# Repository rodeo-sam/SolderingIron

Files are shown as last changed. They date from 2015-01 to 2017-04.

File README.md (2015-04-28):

SolderingIron
=============

Idea for an OpenSource Soldering Iron

This project is just another avr based soldering iron. Since professional equipment is quite pricy and not very complicated this projects takes a good, changeable soldering iron tip like the Weller RT1 and provides all the electronics behind that.

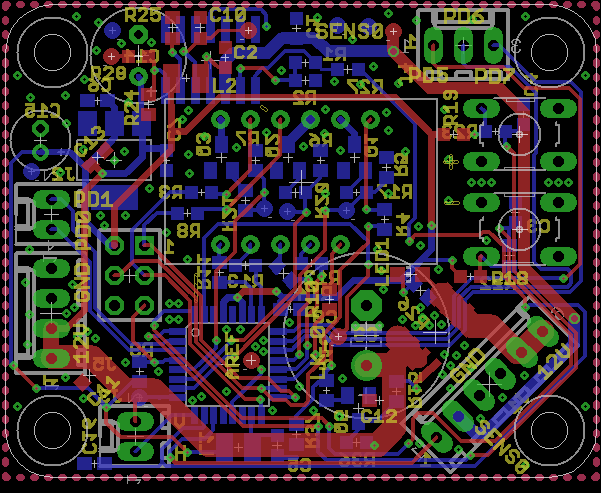
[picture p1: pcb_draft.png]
View on PCB Layout

## Features
* open hardware (schematic and layout made in Eagle 7.2 freeware license)
* open firmware written in C (not ready to use right now)
* fast heatup
* saving and restoring temperature to and from EEPROM
* high-precision op-amp for temperature measurement
* safety measures against overheating and controller crashes
* automatic temperature control (pid controller)
* different temperature scales available (recompiling necessary)
* solder tip rest detection via hall sensor (optional)
* almost all parts are available from the [Seeedstudio Open Parts Library](http://www.seeedstudio.com/wiki/Open_parts_library)

## How does it work
* 5V for logic
* 12V for soldering iron
* ATmega328p controlled

### Temperature measure
The thermo-voltage signal is amplified by an op-amp with a gain
	`g = 1 + R1/R2 = 1 + 51k/100 = 511`
this signal is converted by ADC0 using Vcc=5V as voltage reference

### Solder tip detection
Solved by a hall sensor connected to ADC2. This sensor is powered by 5V

## References
### Links:
* [arduino uno shield](http://www.martin-kumm.de/wiki/doku.php?id=Projects:SMD_Solderstation)
  * Forum discussion + group order coordination [Thema: DIY SMD - Lötstation Ersatz für (WELLER)](http://fpv-community.de/showthread.php?41335-DIY-SMD-Lötstation-Ersatz-für-(WELLER))
* [original Weller cable](http://www.pewa.de/cgi-bin/cosmoshop/lshop.cgi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)
* unfinished project [Custom Weller WSM 1 style controller for RT series tips](http://dangerousprototypes.com/forum/viewtopic.php?f=19&t=3583)
* [Thermoelement im Weller WMRP.](http://www.mikrocontroller.net/topic/175412#1686071)

### Datasheets:
* power MOSFET [IRF7424](http://www.irf.com/product-info/datasheets/data/irf7424.pdf)
* Voltage regulator [REG1117](http://www.ti.com/lit/pdf/SBVS001)
* uC [ATmega328P](http://www.atmel.com/devices/atmega328p.aspx)
* Quad OP-Amp [LM324D](http://pdf1.alldatasheet.com/datasheet-pdf/view/22759/STMICROELECTRONICS/LM324D.html)
* Single OP-Amp [OPA336u](http://www.ti.com/lit/ds/symlink/opa336.pdf)
* Solder Tip [Weller RT1](http://datasheet.octopart.com/RT1-Cooper-Tools-datasheet-13539183.pdf)
* Solder Tip detector [Hallsensor unipolar](http://www.reichelt.de/index.html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)

### Current State:
* hardware version 1.2 is almost ready to be produced
* optimized bill of materials by reducing unnecessary components
* PCB measures 5cm x 5cm
* individual 7-segment displays in use (broader availability)
* I2C is now unused and can be used for additional hardware

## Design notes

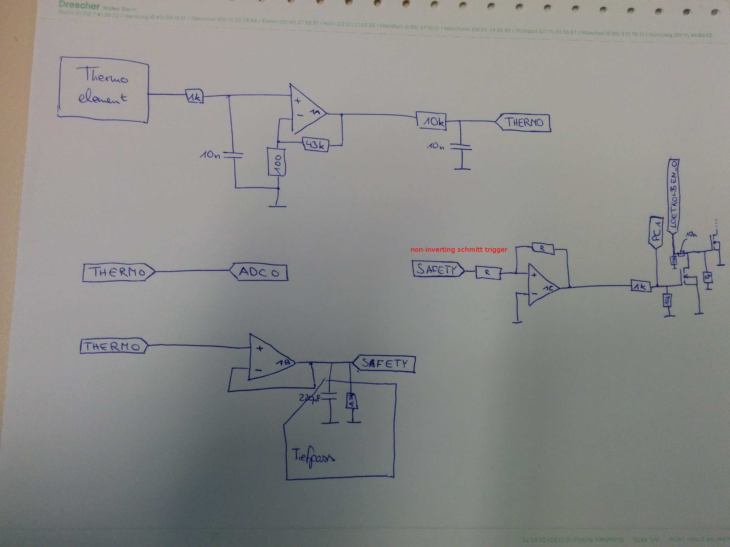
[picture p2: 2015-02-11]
Hardware/img/safety.jpg

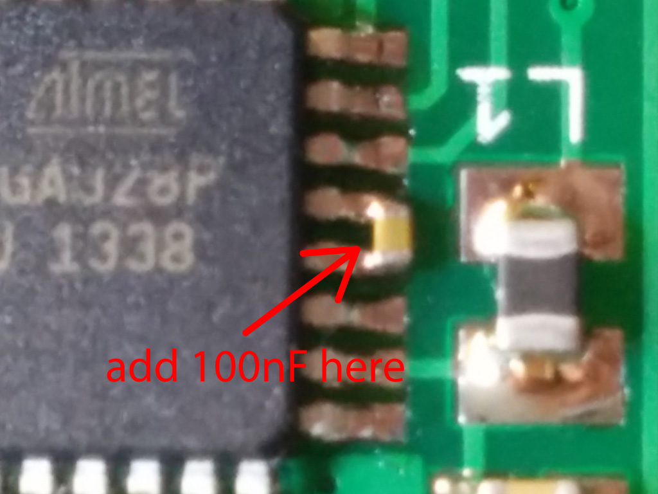
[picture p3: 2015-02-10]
Hardware/img/aref.jpg

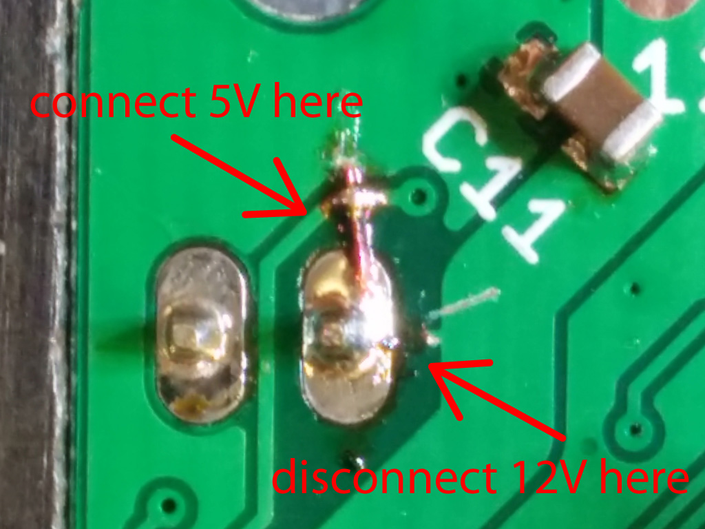
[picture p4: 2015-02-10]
Hardware/img/hall.jpg

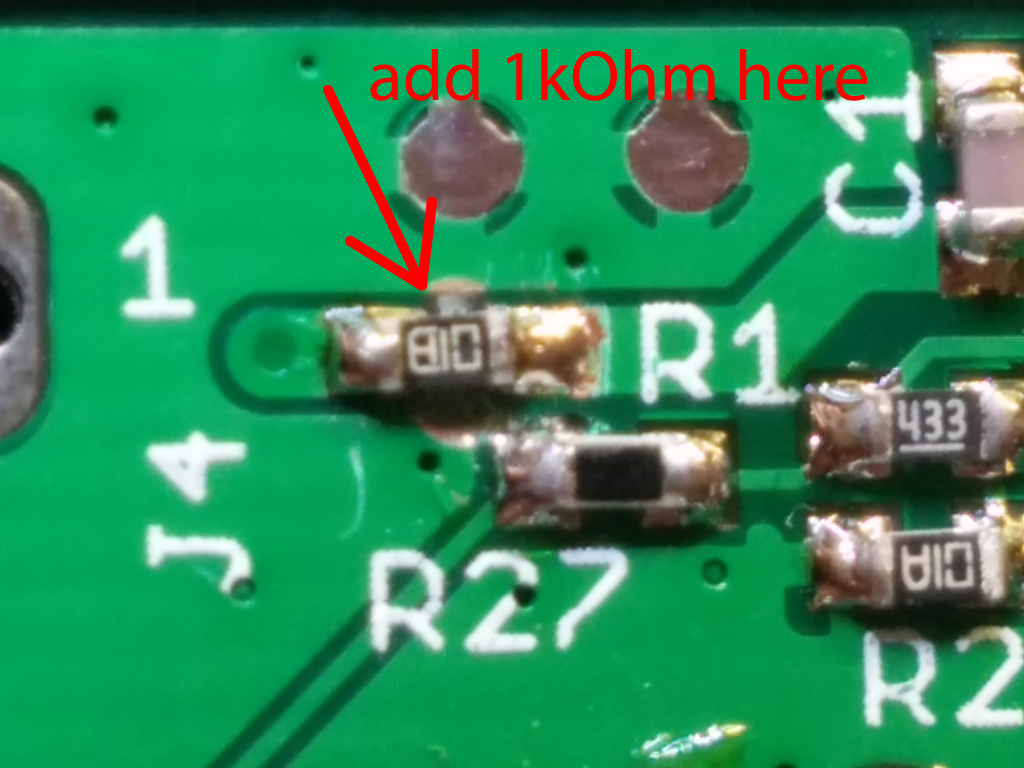
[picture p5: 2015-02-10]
Hardware/img/low_pass.jpg

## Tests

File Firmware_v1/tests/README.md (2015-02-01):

SolderingIron tests
=============

This is the place to store your unit test like test files

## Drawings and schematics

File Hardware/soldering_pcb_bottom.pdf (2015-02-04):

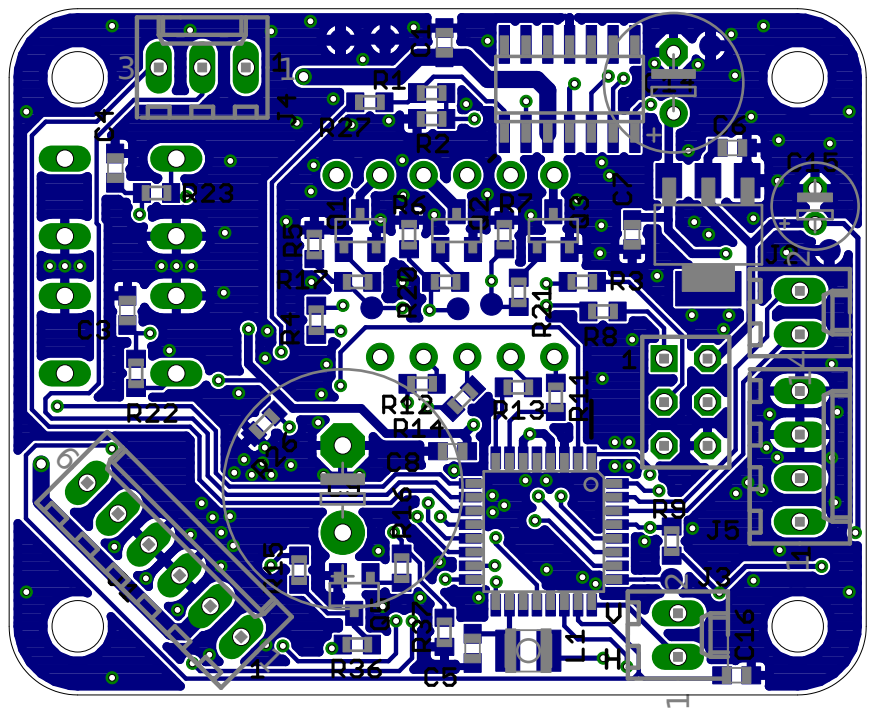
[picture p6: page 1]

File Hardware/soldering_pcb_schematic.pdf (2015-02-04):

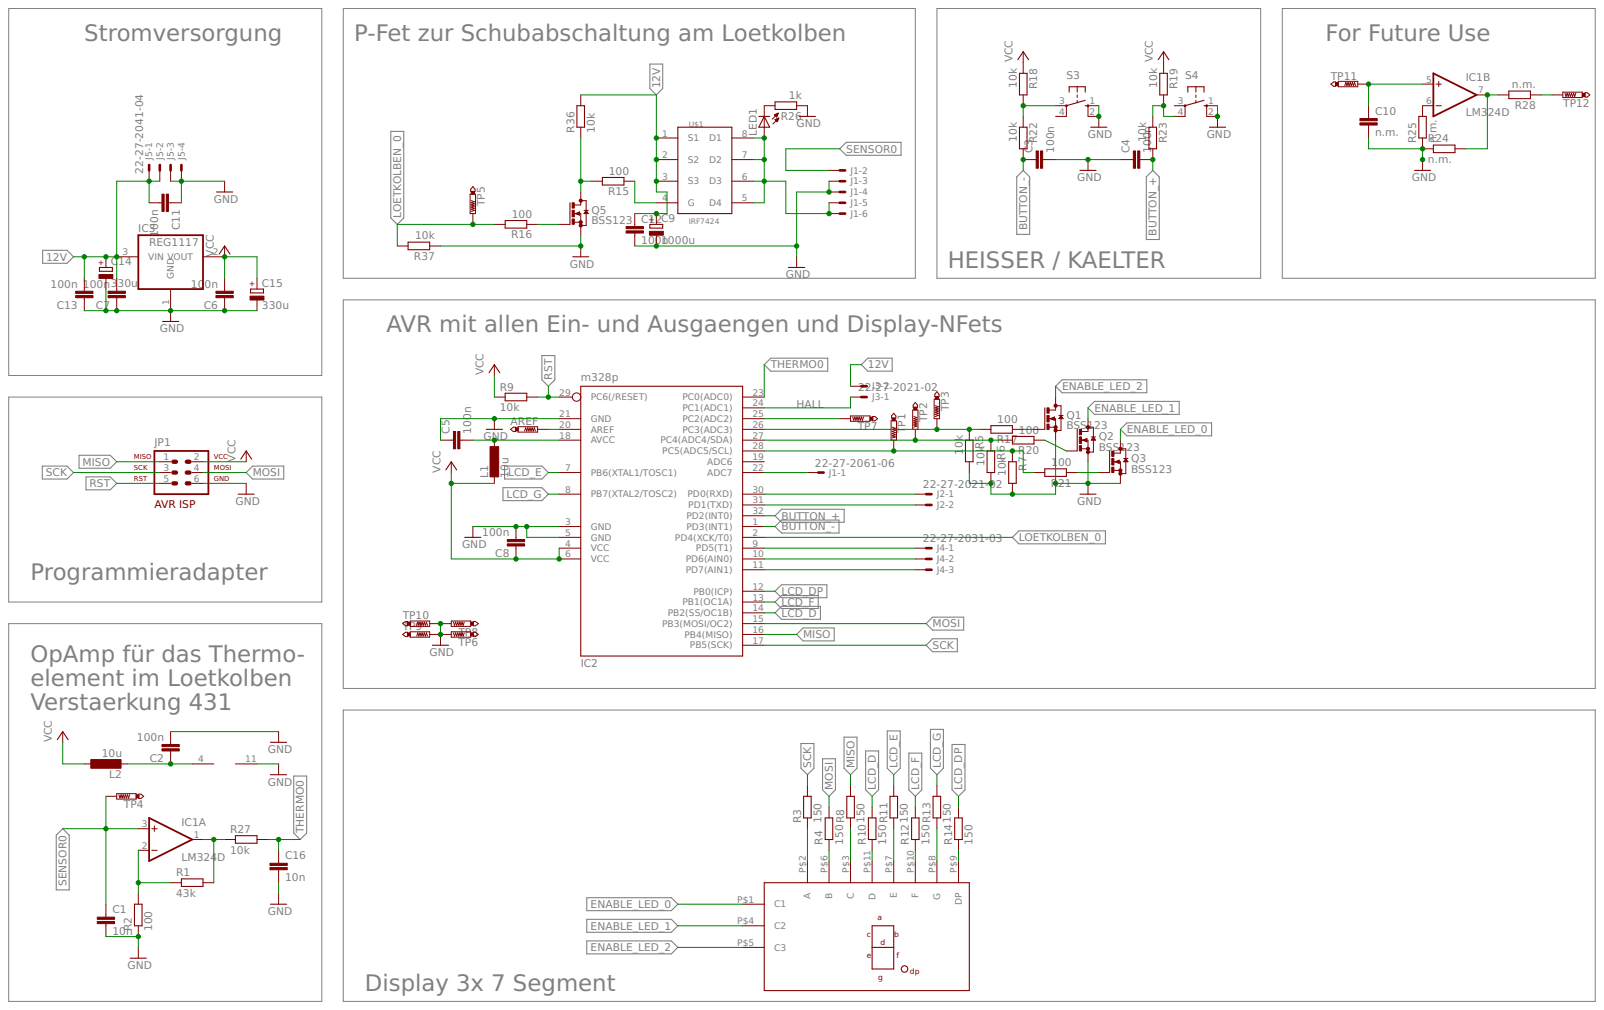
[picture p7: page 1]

AVR mit allen Ein- und Ausgaengen und Display-NFets

OpAmp für das Thermo- element im Loetkolben
Verstaerkung 431

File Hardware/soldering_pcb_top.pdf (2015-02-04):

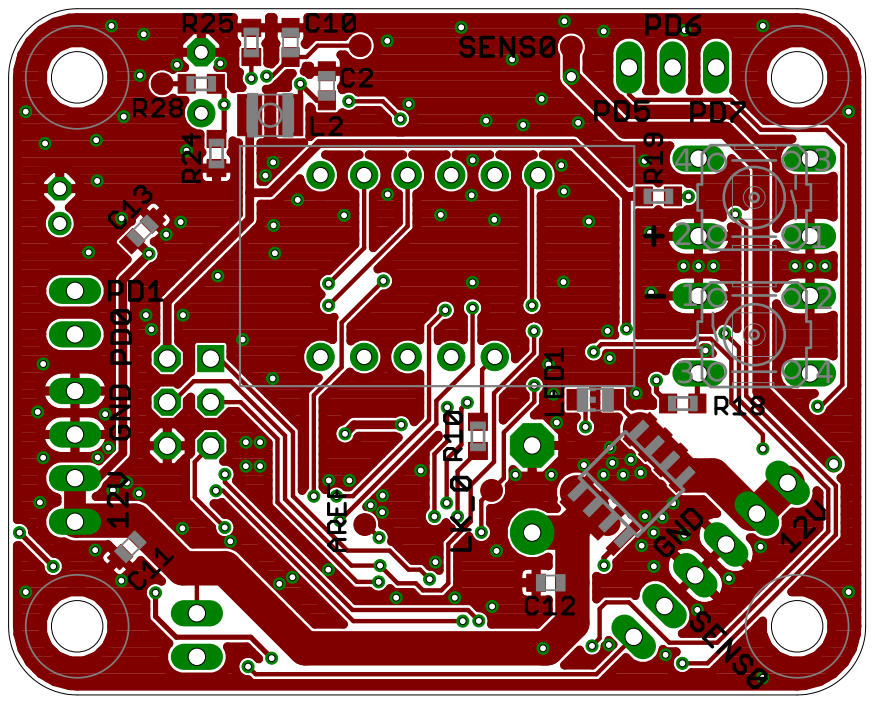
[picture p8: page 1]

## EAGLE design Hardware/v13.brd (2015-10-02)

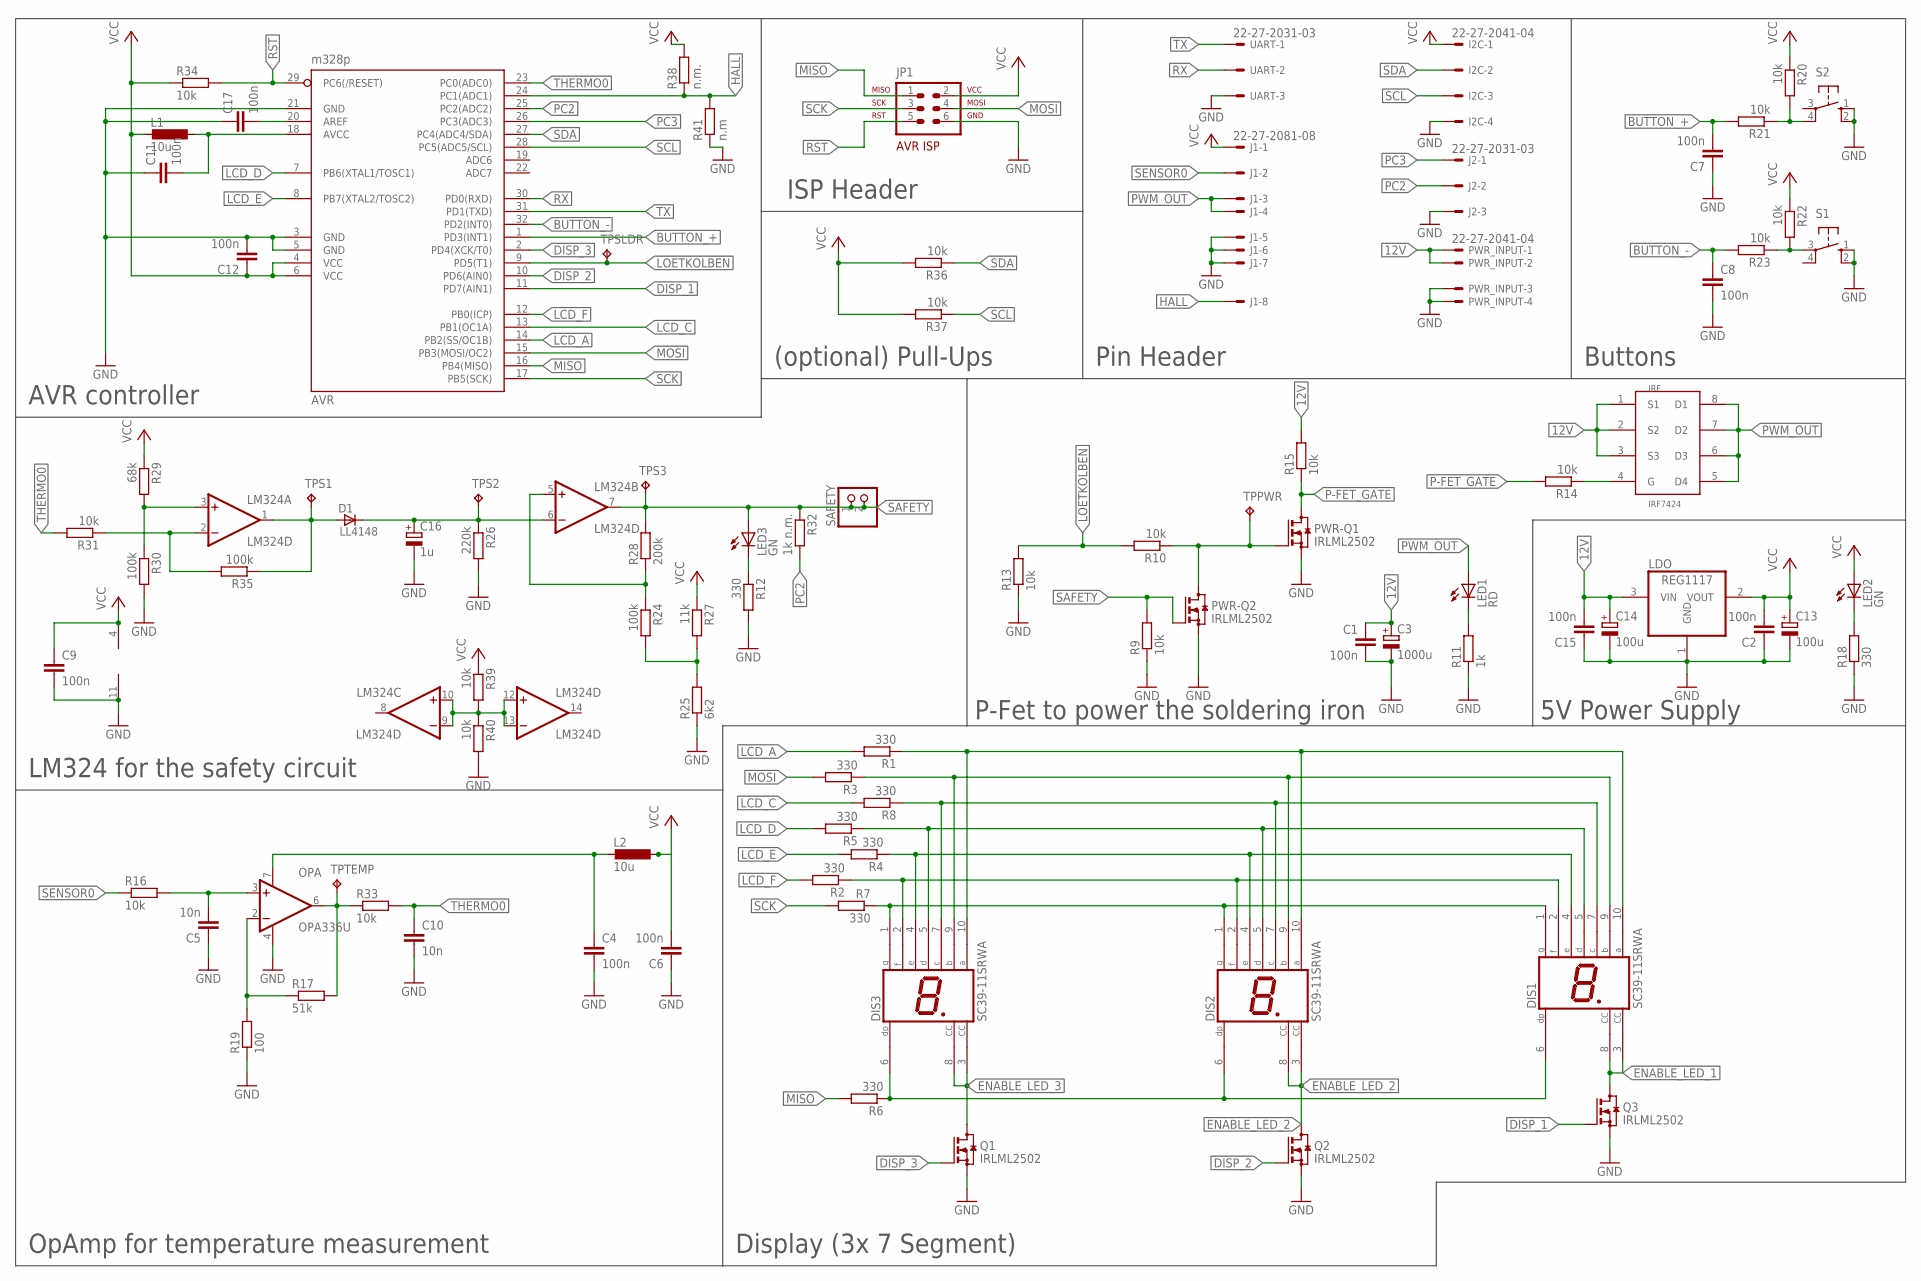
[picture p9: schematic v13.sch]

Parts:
AVR: m328p; TQFP32-08
C1, C2, C4, C6, C7, C8, C9, C11, C12, C15, C17: 100n; C0603
C3: 1000u; E5-13
C5, C10: 10n; C0603
C13, C14: 100u; E2-5
C16: 1u; E2-5
D1: LL4148; SOD80_DO213AA_MINIMELF
DIS1, DIS2, DIS3: SC39-11SRWA; HDSP-E
I2C: 22-27-2041-04; 6410-04
IRF: IRF7424; SO-08
J1: 22-27-2081-08; 6410-08
J2: 22-27-2031-03; 6410-03
JP1: AVR-ISP-6VERT; AVR-ISP-6
L1, L2: 10u; L2825P
LDO: REG1117; SOT223
LED1: RD; CHIP-LED0805
LED2, LED3: GN; CHIP-LED0805
LM324: LM324D; SO14
OPA: OPA336U; SO08
PWR-Q1, PWR-Q2: IRLML2502; SOT23
PWR_INPUT: 22-27-2041-04; 6410-04
Q1, Q2, Q3: IRLML2502; SOT23
R1, R2, R3, R4, R5, R6, R7, R8, R12, R18: 330; R0603
R9, R10, R13, R14, R15, R16, R20, R21, R22, R23, R31, R33, R34, R36, R37, R39, R40: 10k; R0603
R11: 1k; R0603
R17: 51k; R0603
R19: 100; R0603
R24, R30, R35: 100k; R0603
R25: 6k2; R0603
R26: 220k; R0603
R27: 11k; R0603
R28: 200k; R0603
R29: 68k; R0603
R32: 1k n.m.; R0603
R38: n.m.; R0603
R41: n.m; R0603
S1, S2: 10-XX; B3F-10XX
SAFETY: PINHD-1X2; 1X02
TPPWR: TPB1,27; B1,27
TPS1, TPS2, TPS3: TPB1,27; B1,27
TPSLDR: TPB1,27; B1,27
TPTEMP: TPB1,27; B1,27
UART: 22-27-2031-03; 6410-03

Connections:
12V: C1.1, C3.+, C14.+, C15.2, IRF.1 (S1), IRF.2 (S2), IRF.3 (S3), LDO.3 (VIN), PWR_INPUT.1, PWR_INPUT.2, R15.2
AREF: AVR.20 (AREF), C17.2
AVCC: AVR.18 (AVCC), C11.2, L1.1
BUTTON_+: AVR.1 (PD3(INT1)), C7.2, R21.2
BUTTON_-: AVR.32 (PD2(INT0)), C8.1, R23.2
DISP_1: AVR.11 (PD7(AIN1)), Q3.1 (G)
DISP_2: AVR.10 (PD6(AIN0)), Q2.1 (G)
DISP_3: AVR.2 (PD4(XCK/T0)), Q1.1 (G)
ENABLE_LED_1: DIS1.3 (CC), DIS1.8 (CC), Q3.3 (D)
ENABLE_LED_2: DIS2.3 (CC), DIS2.8 (CC), Q2.3 (D)
ENABLE_LED_3: DIS3.3 (CC), DIS3.8 (CC), Q1.3 (D)
GND: AVR.3 (GND), AVR.5 (GND), AVR.21 (GND), C1.2, C2.1, C3.-, C4.2, C5.1, C6.1, C7.1, C8.2, C9.2, C10.2, C11.1, C12.2, C13.-, C14.-, C15.1, C16.-, C17.1, I2C.4, J1.5, J1.6, J1.7, J2.3, JP1.6, LDO.1 (GND), LM324.11 (V-), OPA.4 (V-), PWR-Q1.2 (S), PWR-Q2.2 (S), PWR_INPUT.3, PWR_INPUT.4, Q1.2 (S), Q2.2 (S), Q3.2 (S), R9.1, R11.1, R12.2, R13.1, R18.1, R19.1, R25.1, R26.2, R30.2, R40.2, R41.1, S1.1 (S), S1.2 (S1), S2.1 (S), S2.2 (S1), UART.3
HALL: AVR.24 (PC1(ADC1)), J1.8, R38.1, R41.2
LCD_A: AVR.14 (PB2(SS/OC1B)), R1.2
LCD_C: AVR.13 (PB1(OC1A)), R8.2
LCD_D: AVR.7 (PB6(XTAL1/TOSC1)), R5.2
LCD_E: AVR.8 (PB7(XTAL2/TOSC2)), R4.2
LCD_F: AVR.12 (PB0(ICP)), R2.2
LOETKOLBEN: AVR.9 (PD5(T1)), R10.2, R13.2, TPSLDR.TP
MISO: AVR.16 (PB4(MISO)), JP1.1, R6.2
MOSI: AVR.15 (PB3(MOSI/OC2)), JP1.4, R3.2
unnamed: OPA.2 (-IN), R17.1, R19.2
unnamed: LED3.C, R12.1
unnamed: LM324.2 (-IN), R31.1, R35.2
unnamed: LM324.9 (-IN), LM324.10 (+IN), LM324.12 (+IN), LM324.13 (-IN), R39.2, R40.1
unnamed: C4.1, L2.2, OPA.7 (V+)
unnamed: D1.A, LM324.1 (OUT), R35.1, TPS1.TP
unnamed: LM324.3 (+IN), R29.2, R30.1
unnamed: C16.+, D1.C, LM324.6 (-IN), R26.1, TPS2.TP
unnamed: LM324.5 (+IN), R24.1, R28.1
unnamed: R24.2, R25.2, R27.2
unnamed: IRF.4 (G), R14.1
unnamed: PWR-Q1.1 (G), PWR-Q2.3 (D), R10.1, TPPWR.TP
unnamed: R22.2, R23.1, S1.3
unnamed: R20.2, R21.1, S2.4 (P1)
unnamed: LED2.C, R18.2
unnamed: LED1.C, R11.2
unnamed: C5.2, OPA.3 (+IN), R16.2
unnamed: DIS1.6 (DP), DIS2.6 (DP), DIS3.6 (DP), R6.1
unnamed: DIS1.2 (F), DIS2.2 (F), DIS3.2 (F), R2.1
unnamed: DIS1.1 (G), DIS2.1 (G), DIS3.1 (G), R7.1
unnamed: DIS1.4 (E), DIS2.4 (E), DIS3.4 (E), R4.1
unnamed: DIS1.5 (D), DIS2.5 (D), DIS3.5 (D), R5.1
unnamed: DIS1.7 (C), DIS2.7 (C), DIS3.7 (C), R8.1
unnamed: DIS1.9 (B), DIS2.9 (B), DIS3.9 (B), R3.1
unnamed: DIS1.10 (A), DIS2.10 (A), DIS3.10 (A), R1.1
OPA_OUT: OPA.6 (OUT), R17.2, R33.1, TPTEMP.TP
P-FET_GATE: PWR-Q1.3 (D), R14.2, R15.1
PC2: AVR.25 (PC2(ADC2)), J2.2, R32.2
PC3: AVR.26 (PC3(ADC3)), J2.1
PWM_OUT: IRF.5 (D4), IRF.6 (D3), IRF.7 (D2), IRF.8 (D1), J1.3, J1.4, LED1.A
RST: AVR.29 (PC6(/RESET)), JP1.5, R34.2
RX: AVR.30 (PD0(RXD)), UART.2
SAFETY: LED3.A, LM324.7 (OUT), PWR-Q2.1 (G), R9.2, R28.2, R32.1, SAFETY.1, SAFETY.2, TPS3.TP
SCK: AVR.17 (PB5(SCK)), JP1.3, R7.2
SCL: AVR.28 (PC5(ADC5/SCL)), I2C.3, R37.1
SDA: AVR.27 (PC4(ADC4/SDA)), I2C.2, R36.1
SENSOR0: J1.2, R16.1
THERMO0: AVR.23 (PC0(ADC0)), C10.1, R31.2, R33.2
TX: AVR.31 (PD1(TXD)), UART.1
VCC: AVR.4 (VCC), AVR.6 (VCC), C2.2, C6.2, C9.1, C12.1, C13.+, I2C.1, J1.1, JP1.2, L1.2, L2.1, LDO.2 (VOUT), LED2.A, LM324.4 (V+), R20.1, R22.1, R27.1, R29.1, R34.1, R36.2, R37.2, R38.2, R39.1

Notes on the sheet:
Buttons
AVR controller
P-Fet to power the soldering iron
5V Power Supply
ISP Header
OpAmp for temperature measurement
Display (3x 7 Segment)
Pin Header
LM324 for the safety circuit
(optional) Pull-Ups

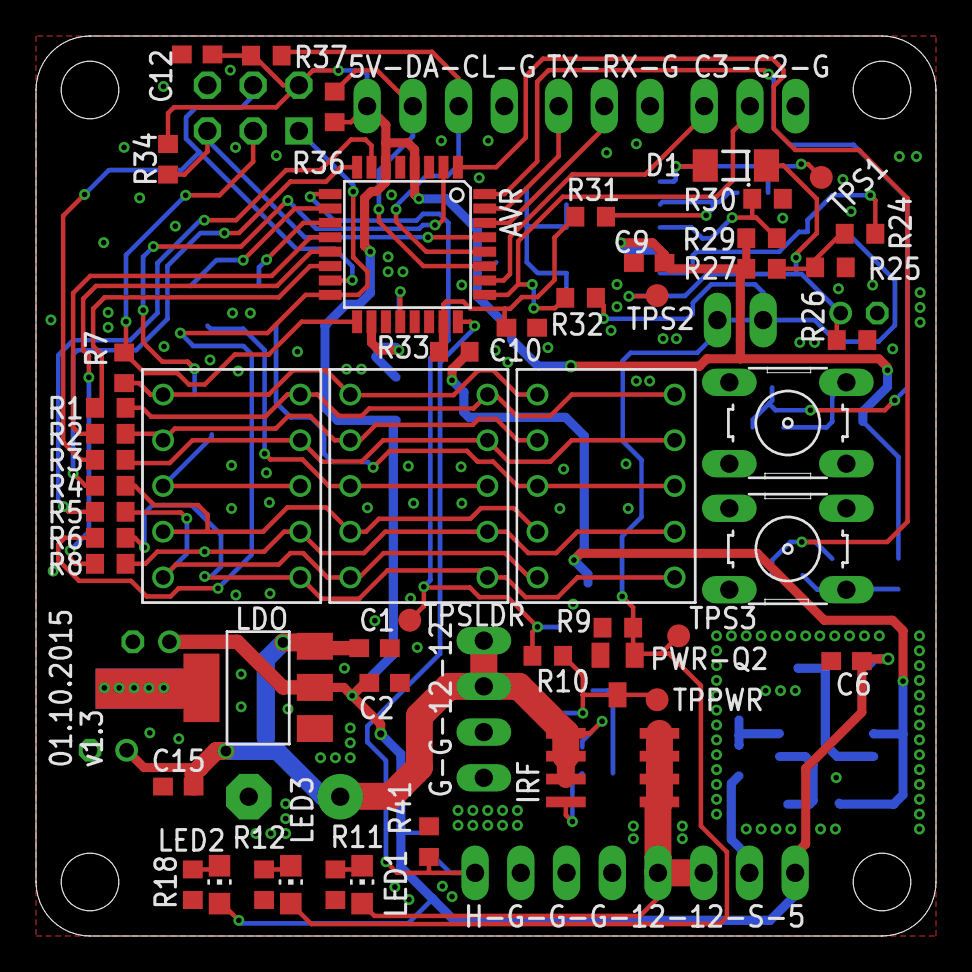
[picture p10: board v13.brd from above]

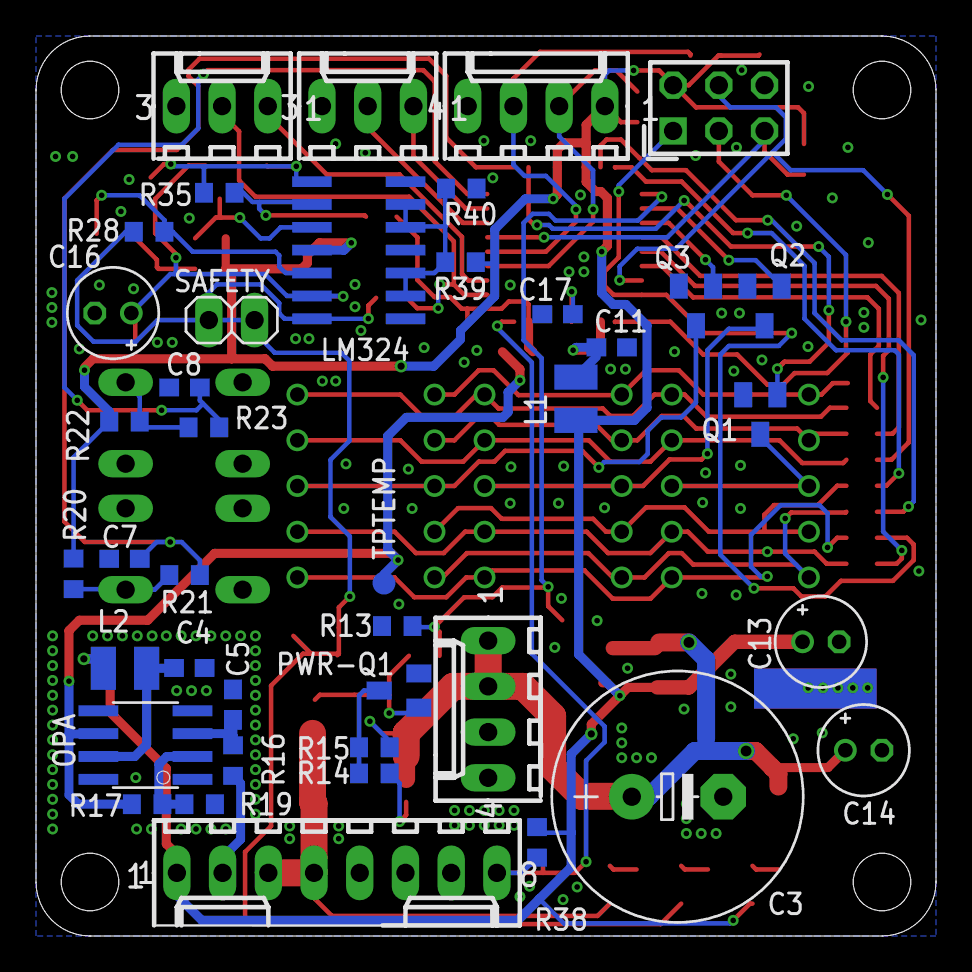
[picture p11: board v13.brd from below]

Board: 4 copper layers, 50.0 x 50.0 mm, 92 parts (41 on the bottom side), 61 nets.

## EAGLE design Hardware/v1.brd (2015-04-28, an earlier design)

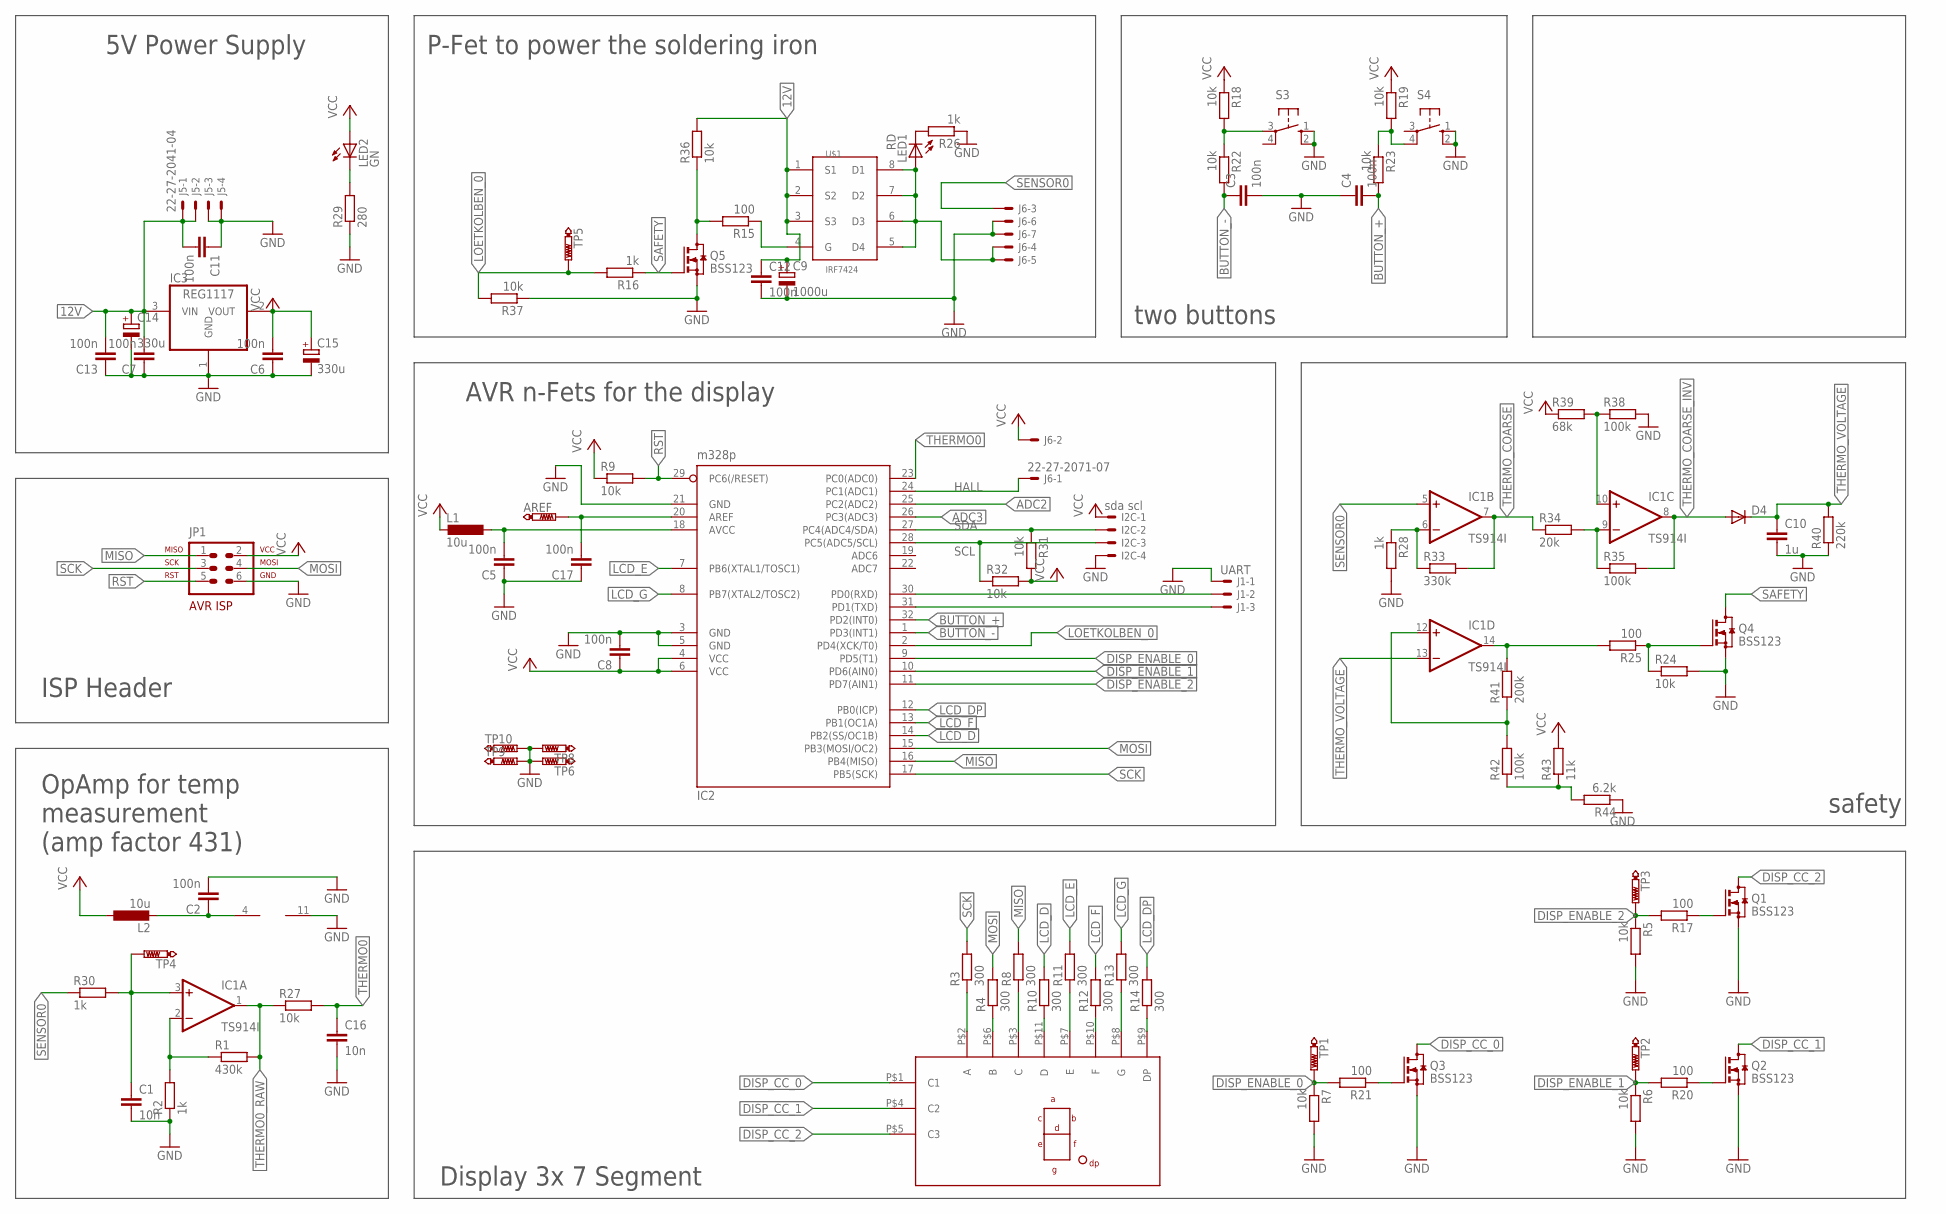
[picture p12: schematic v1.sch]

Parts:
AREF: PTR1B1,27; B1,27
C1, C16: 10n; C0603
C2, C3, C4, C5, C6, C7, C8, C11, C12, C13, C17: 100n; C0603
C9: 1000u; E5-13
C10: 1u; C0805
C14: 330u; E3,5-8
C15: 330u; E2-5
D4: DIODE-DO214AC; DO214AC
I2C: sda scl; 6410-04
IC1: TS914I; SO14
IC2: m328p; TQFP32-08
IC3: REG1117; SOT223
J1: UART; 6410-03
J5: 22-27-2041-04; 6410-04
J6: 22-27-2071-07; 6410-07
JP1: AVR-ISP-6VERT; AVR-ISP-6
L1, L2: 10u; L2825P
LED1: RD; CHIP-LED0805
LED2: GN; CHIP-LED0805
Q1, Q2, Q3, Q4, Q5: BSS123; SOT23
R1: 430k; R0603
R2, R16, R26, R28, R30: 1k; R0603
R3, R4, R8, R10, R11, R12, R13, R14: 300; R0603
R5, R6, R7, R9, R18, R19, R22, R23, R24, R27, R31, R32, R36, R37: 10k; R0603
R15, R17, R20, R21, R25: 100; R0603
R29: 280; R0603
R33: 330k; R0603
R34: 20k; R0603
R35, R38, R42: 100k; R0603
R39: 68k; R0603
R40: 220k; R0603
R41: 200k; R0603
R43: 11k; R0603
R44: 6.2k; R0603
S3, S4: 10-XX; B3F-10XX
TP1, TP2, TP3, TP4, TP5, TP6, TP8, TP9, TP10: PTR1B1,27; B1,27
U$1: IRF7424; SO-08
U$2: 3X7SEG

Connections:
12V: C7.2, C9.+, C11.2, C12.1, C13.2, C14.+, IC3.3 (VIN), J5.1, J5.2, R36.2, U$1.1 (S1), U$1.2 (S2), U$1.3 (S3)
ADC2: IC2.25 (PC2(ADC2))
ADC3: IC2.26 (PC3(ADC3))
AREF: AREF.TP, C17.2, IC2.20 (AREF)
BUTTON_+: C4.2, IC2.32 (PD2(INT0)), R23.2
BUTTON_-: C3.1, IC2.1 (PD3(INT1)), R22.2
DISP_CC_0: Q3.3 (D), U$2.P$1 (C1)
DISP_CC_1: Q2.3 (D), U$2.P$4 (C2)
DISP_CC_2: Q1.3 (D), U$2.P$5 (C3)
DISP_ENABLE_0: IC2.9 (PD5(T1)), R7.1, R21.2, TP1.TP
DISP_ENABLE_1: IC2.10 (PD6(AIN0)), R6.1, R20.2, TP2.TP
DISP_ENABLE_2: IC2.11 (PD7(AIN1)), R5.1, R17.2, TP3.TP
GND: C1.2, C2.2, C3.2, C4.1, C5.1, C6.1, C7.1, C8.2, C9.-, C10.2, C11.1, C12.2, C13.1, C14.-, C15.-, C16.2, C17.1, I2C.4, IC1.11 (V-), IC2.3 (GND), IC2.5 (GND), IC2.21 (GND), IC3.1 (GND), J1.1, J5.3, J5.4, J6.6, J6.7, JP1.6, Q1.2 (S), Q2.2 (S), Q3.2 (S), Q4.2 (S), Q5.2 (S), R2.1, R5.2, R6.2, R7.2, R24.2, R26.1, R28.2, R29.1, R37.1, R38.2, R40.1, R44.1, S3.1 (S), S3.2 (S1), S4.1 (S), S4.2 (S1), TP6.TP, TP8.TP, TP9.TP, TP10.TP
HALL: IC2.24 (PC1(ADC1)), J6.1
LCD_D: IC2.14 (PB2(SS/OC1B)), R10.2
LCD_DP: IC2.12 (PB0(ICP)), R14.2
LCD_E: IC2.7 (PB6(XTAL1/TOSC1)), R11.2
LCD_F: IC2.13 (PB1(OC1A)), R12.2
LCD_G: IC2.8 (PB7(XTAL2/TOSC2)), R13.2
LOETKOLBEN_0: IC2.2 (PD4(XCK/T0)), R16.2, R37.2, TP5.TP
MISO: IC2.16 (PB4(MISO)), JP1.1, R8.2
MOSI: IC2.15 (PB3(MOSI/OC2)), JP1.4, R4.2
unnamed: IC1.2 (-IN), R1.1, R2.2
unnamed: IC2.31 (PD1(TXD)), J1.3
unnamed: C5.2, IC2.18 (AVCC), L1.1
unnamed: IC2.30 (PD0(RXD)), J1.2
unnamed: C2.1, IC1.4 (V+), L2.2
unnamed: R3.1, U$2.P$2 (A)
unnamed: R4.1, U$2.P$6 (B)
unnamed: R8.1, U$2.P$3 (C)
unnamed: R10.1, U$2.P$11 (D)
unnamed: Q4.1 (G), R24.1, R25.1
unnamed: R11.1, U$2.P$7 (E)
unnamed: R12.1, U$2.P$10 (F)
unnamed: R13.1, U$2.P$8 (G)
unnamed: R14.1, U$2.P$9 (DP)
unnamed: R15.1, U$1.4 (G)
unnamed: IC1.6 (-IN), R28.1, R33.1
unnamed: Q2.1 (G), R20.1
unnamed: Q1.1 (G), R17.1
unnamed: Q3.1 (G), R21.1
unnamed: IC1.9 (-IN), R34.2, R35.1
unnamed: IC1.12 (+IN), R41.1, R42.2
unnamed: R18.2, R22.1, S3.3
unnamed: R19.2, R23.1, S4.4 (P1)
unnamed: LED2.C, R29.2
unnamed: LED1.C, R26.2
unnamed: IC1.10 (+IN), R38.1, R39.2
unnamed: C1.1, IC1.3 (+IN), R30.2, TP4.TP
unnamed: R42.1, R43.1, R44.2
unnamed: IC1.14 (OUT), R25.2, R41.2
unnamed: Q5.3 (D), R15.2, R36.1
unnamed: J6.4, J6.5, LED1.A, U$1.5 (D4), U$1.6 (D3), U$1.7 (D2), U$1.8 (D1)
RST: IC2.29 (PC6(/RESET)), JP1.5, R9.2
SAFETY: Q4.3 (D), Q5.1 (G), R16.1
SCK: IC2.17 (PB5(SCK)), JP1.3, R3.2
SCL: I2C.3, IC2.28 (PC5(ADC5/SCL)), R32.1
SDA: I2C.2, IC2.27 (PC4(ADC4/SDA)), R31.1
SENSOR0: IC1.5 (+IN), J6.3, R30.1
THERMO0: C16.1, IC2.23 (PC0(ADC0)), R27.2
THERMO0_RAW: IC1.1 (OUT), R1.2, R27.1
THERMO_COARSE: IC1.7 (OUT), R33.2, R34.1
THERMO_COARSE_INV: D4.A, IC1.8 (OUT), R35.2
THERMO_VOLTAGE: C10.1, D4.C, IC1.13 (-IN), R40.2
VCC: C6.2, C8.1, C15.+, I2C.1, IC2.4 (VCC), IC2.6 (VCC), IC3.2 (VOUT), J6.2, JP1.2, L1.2, L2.1, LED2.A, R9.1, R18.1, R19.1, R31.2, R32.2, R39.1, R43.2

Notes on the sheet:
two buttons
AVR n-Fets for the display
P-Fet to power the soldering iron
5V Power Supply
ISP Header
OpAmp for temp measurement (amp factor 431)
Display 3x 7 Segment
safety

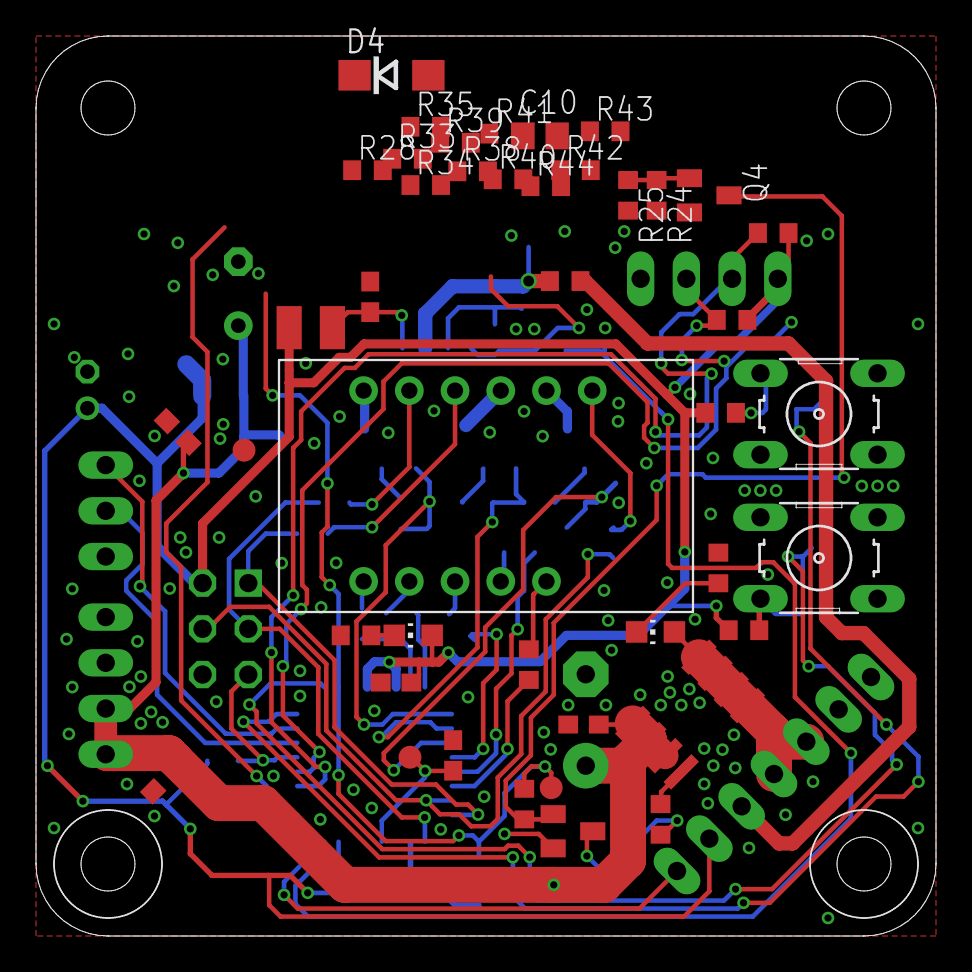
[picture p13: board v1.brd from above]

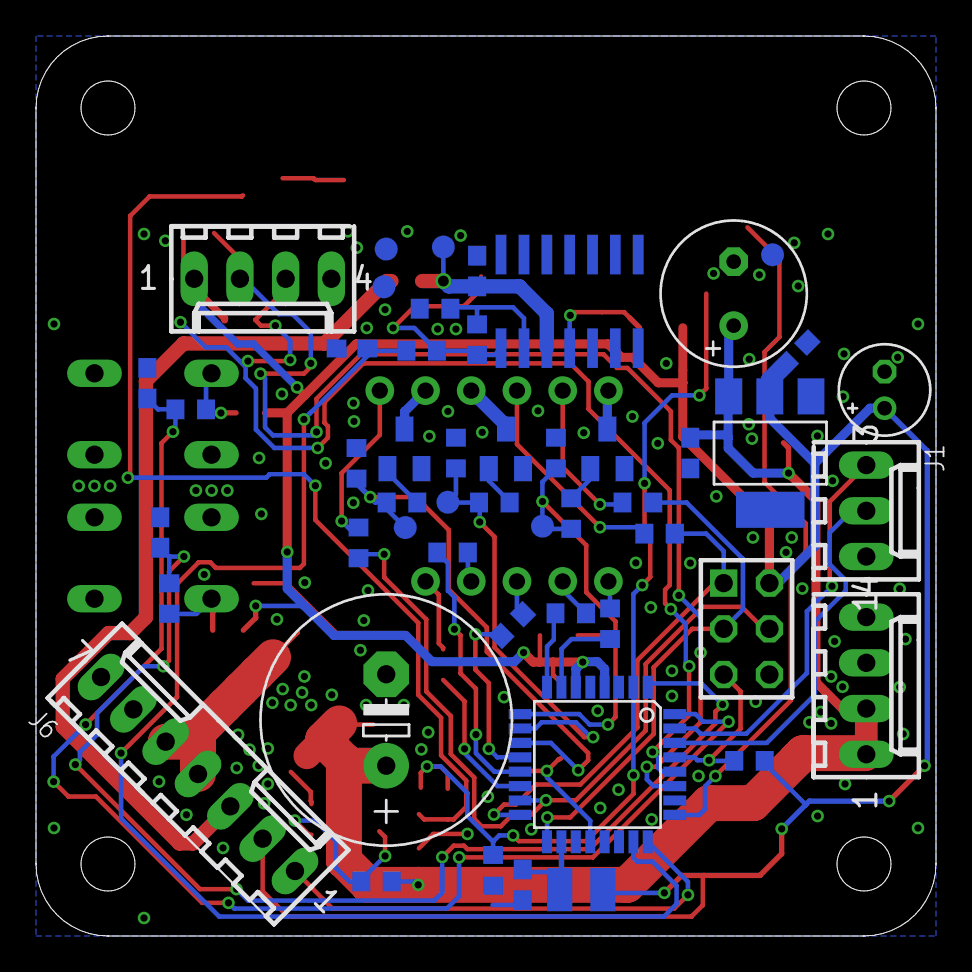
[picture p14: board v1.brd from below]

Board: 2 copper layers, 50.0 x 50.0 mm, 93 parts (50 on the bottom side), 63 nets.

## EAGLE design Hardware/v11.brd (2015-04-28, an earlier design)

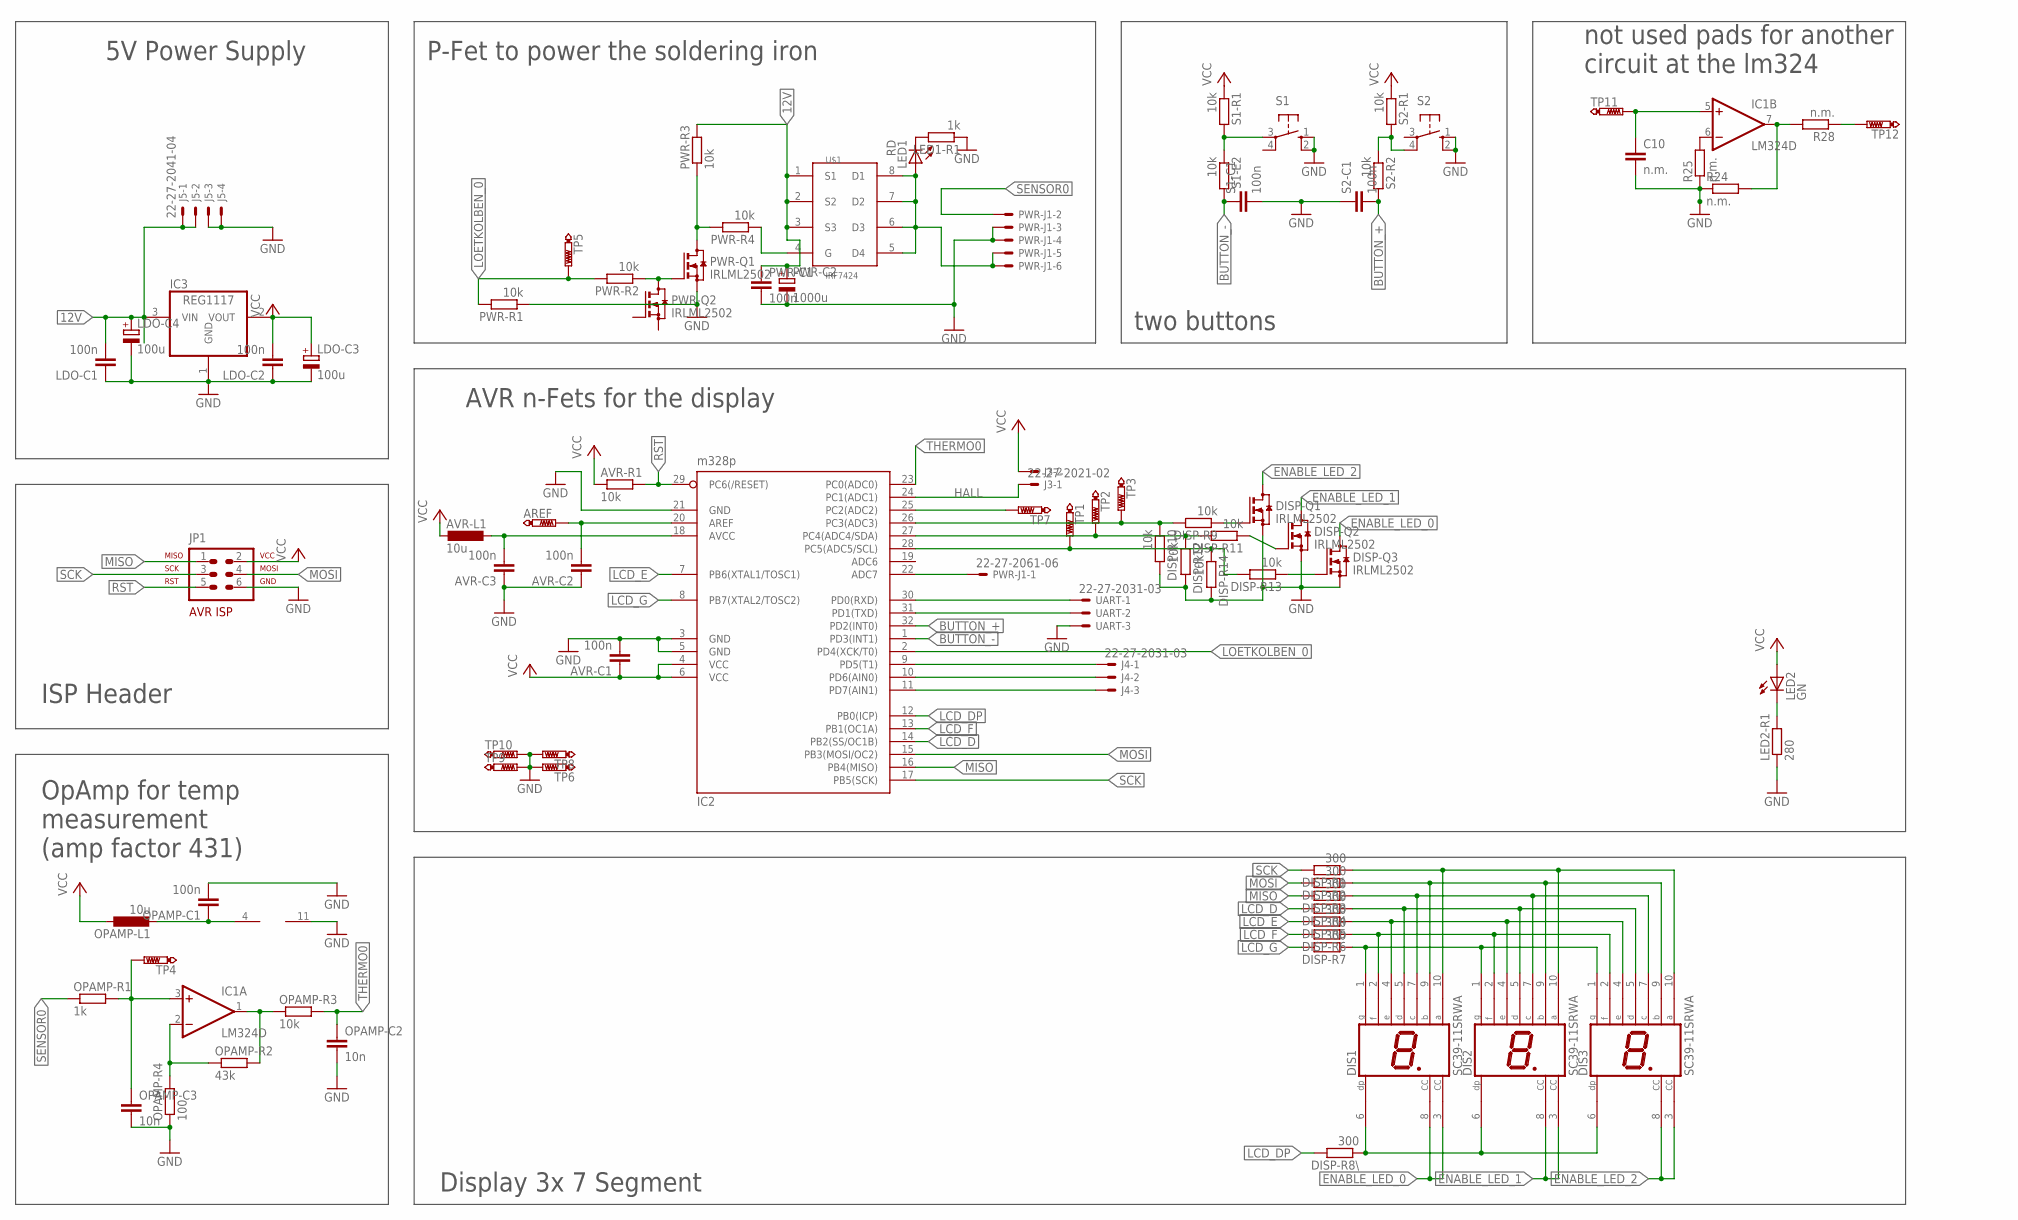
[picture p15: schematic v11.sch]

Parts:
AREF: PTR1B1,27; B1,27
AVR-C1, AVR-C2, AVR-C3: 100n; C0603
AVR-L1: 10u; L2825P
AVR-R1: 10k; R0603
C10: n.m.; C0603
DIS1, DIS2, DIS3: SC39-11SRWA; HDSP-E
DISP-Q1, DISP-Q2, DISP-Q3: IRLML2502; SOT23
DISP-R1, DISP-R2, DISP-R3, DISP-R4, DISP-R5, DISP-R6, DISP-R7, DISP-R8\: 300; R0603
DISP-R9, DISP-R10, DISP-R11, DISP-R12, DISP-R13, DISP-R14: 10k; R0603
IC1: LM324D; SO14
IC2: m328p; TQFP32-08
IC3: REG1117; SOT223
J3: 22-27-2021-02; 6410-02
J4: 22-27-2031-03; 6410-03
J5: 22-27-2041-04; 6410-04
JP1: AVR-ISP-6VERT; AVR-ISP-6
LDO-C1, LDO-C2: 100n; C0603
LDO-C3, LDO-C4: 100u; E2-5
LED1: RD; CHIP-LED0805
LED1-R1: 1k; R0603
LED2: GN; CHIP-LED0805
LED2-R1: 280; R0603
OPAMP-C1: 100n; C0603
OPAMP-C2, OPAMP-C3: 10n; C0603
OPAMP-L1: 10u; L2825P
OPAMP-R1: 1k; R0603
OPAMP-R2: 43k; R0603
OPAMP-R3: 10k; R0603
OPAMP-R4: 100; R0603
PWR-C1: 100n; C0603
PWR-C2: 1000u; E5-13
PWR-J1: 22-27-2061-06; 6410-06
PWR-Q1, PWR-Q2: IRLML2502; SOT23
PWR-R1, PWR-R2, PWR-R3, PWR-R4: 10k; R0603
R24, R25, R28: n.m.; R0603
S1, S2: 10-XX; B3F-10XX
S1-C1, S2-C1: 100n; C0603
S1-E2, S1-R1, S2-R1, S2-R2: 10k; R0603
TP1, TP2, TP3, TP4, TP5, TP6, TP7, TP8, TP9, TP10, TP11, TP12: PTR1B1,27; B1,27
U$1: IRF7424; SO-08
UART: 22-27-2031-03; 6410-03

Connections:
12V: IC3.3 (VIN), J5.1, J5.2, LDO-C1.2, LDO-C4.+, PWR-C1.1, PWR-C2.+, PWR-R3.2, U$1.1 (S1), U$1.2 (S2), U$1.3 (S3)
ADC2: IC2.25 (PC2(ADC2)), TP7.TP
ADC7: IC2.22 (ADC7), PWR-J1.1
AREF: AREF.TP, AVR-C2.2, IC2.20 (AREF)
BUTTON_+: IC2.32 (PD2(INT0)), S2-C1.2, S2-R2.2
BUTTON_-: IC2.1 (PD3(INT1)), S1-C1.1, S1-E2.2
ENABLE_LED_0: DIS1.3 (CC), DIS1.8 (CC), DISP-Q3.3 (D)
ENABLE_LED_1: DIS2.3 (CC), DIS2.8 (CC), DISP-Q2.3 (D)
ENABLE_LED_2: DIS3.3 (CC), DIS3.8 (CC), DISP-Q1.3 (D)
GND: AVR-C1.2, AVR-C2.1, AVR-C3.1, C10.2, DISP-Q1.2 (S), DISP-Q2.2 (S), DISP-Q3.2 (S), DISP-R10.2, DISP-R12.2, DISP-R14.2, IC1.11 (V-), IC2.3 (GND), IC2.5 (GND), IC2.21 (GND), IC3.1 (GND), J5.3, J5.4, JP1.6, LDO-C1.1, LDO-C2.1, LDO-C3.-, LDO-C4.-, LED1-R1.1, LED2-R1.1, OPAMP-C1.2, OPAMP-C2.2, OPAMP-C3.2, OPAMP-R4.1, PWR-C1.2, PWR-C2.-, PWR-J1.3, PWR-J1.4, PWR-Q1.2 (S), PWR-R1.1, R24.1, R25.1, S1.1 (S), S1.2 (S1), S1-C1.2, S2.1 (S), S2.2 (S1), S2-C1.1, TP6.TP, TP8.TP, TP9.TP, TP10.TP, UART.3
HALL: IC2.24 (PC1(ADC1)), J3.1
LCD_D: DISP-R4.2, IC2.14 (PB2(SS/OC1B))
LCD_DP: DISP-R8\.2, IC2.12 (PB0(ICP))
LCD_E: DISP-R5.2, IC2.7 (PB6(XTAL1/TOSC1))
LCD_F: DISP-R6.2, IC2.13 (PB1(OC1A))
LCD_G: DISP-R7.2, IC2.8 (PB7(XTAL2/TOSC2))
LOETKOLBEN_0: IC2.2 (PD4(XCK/T0)), PWR-R1.2, PWR-R2.2, TP5.TP
MISO: DISP-R3.2, IC2.16 (PB4(MISO)), JP1.1
MOSI: DISP-R2.2, IC2.15 (PB3(MOSI/OC2)), JP1.4
unnamed: IC1.2 (-IN), OPAMP-R2.1, OPAMP-R4.2
unnamed: DISP-R9.2, DISP-R10.1, IC2.26 (PC3(ADC3)), TP3.TP
unnamed: AVR-C3.2, AVR-L1.1, IC2.18 (AVCC)
unnamed: DISP-R13.2, DISP-R14.1, IC2.28 (PC5(ADC5/SCL)), TP1.TP
unnamed: IC1.4 (V+), OPAMP-C1.1, OPAMP-L1.2
unnamed: DISP-R11.2, DISP-R12.1, IC2.27 (PC4(ADC4/SDA)), TP2.TP
unnamed: PWR-R4.1, U$1.4 (G)
unnamed: PWR-Q1.1 (G), PWR-Q2.3 (D), PWR-R2.1
unnamed: DISP-Q2.1 (G), DISP-R11.1
unnamed: DISP-Q1.1 (G), DISP-R9.1
unnamed: DISP-Q3.1 (G), DISP-R13.1
unnamed: IC1.6 (-IN), R25.2
unnamed: R28.1, TP12.TP
unnamed: S1.3, S1-E2.1, S1-R1.2
unnamed: S2.4 (P1), S2-R1.2, S2-R2.1
unnamed: LED2.C, LED2-R1.2
unnamed: LED1.C, LED1-R1.2
unnamed: IC1.7 (OUT), R24.2, R28.2
unnamed: IC1.3 (+IN), OPAMP-C3.1, OPAMP-R1.2, TP4.TP
unnamed: IC2.31 (PD1(TXD)), UART.2
unnamed: IC2.30 (PD0(RXD)), UART.1
unnamed: C10.1, IC1.5 (+IN), TP11.TP
unnamed: DIS1.6 (DP), DIS2.6 (DP), DIS3.6 (DP), DISP-R8\.1
unnamed: PWR-Q1.3 (D), PWR-R3.1, PWR-R4.2
unnamed: LED1.A, PWR-J1.5, PWR-J1.6, U$1.5 (D4), U$1.6 (D3), U$1.7 (D2), U$1.8 (D1)
unnamed: DIS1.2 (F), DIS2.2 (F), DIS3.2 (F), DISP-R6.1
unnamed: DIS1.1 (G), DIS2.1 (G), DIS3.1 (G), DISP-R7.1
unnamed: DIS1.4 (E), DIS2.4 (E), DIS3.4 (E), DISP-R5.1
unnamed: DIS1.5 (D), DIS2.5 (D), DIS3.5 (D), DISP-R4.1
unnamed: DIS1.7 (C), DIS2.7 (C), DIS3.7 (C), DISP-R3.1
unnamed: DIS1.9 (B), DIS2.9 (B), DIS3.9 (B), DISP-R2.1
unnamed: DIS1.10 (A), DIS2.10 (A), DIS3.10 (A), DISP-R1.1
PD5: IC2.9 (PD5(T1)), J4.1
PD6: IC2.10 (PD6(AIN0)), J4.2
PD7: IC2.11 (PD7(AIN1)), J4.3
RST: AVR-R1.2, IC2.29 (PC6(/RESET)), JP1.5
SCK: DISP-R1.2, IC2.17 (PB5(SCK)), JP1.3
SDFGHJK: IC1.1 (OUT), OPAMP-R2.2, OPAMP-R3.1
SENSOR0: OPAMP-R1.1, PWR-J1.2
THERMO0: IC2.23 (PC0(ADC0)), OPAMP-C2.1, OPAMP-R3.2
VCC: AVR-C1.1, AVR-L1.2, AVR-R1.1, IC2.4 (VCC), IC2.6 (VCC), IC3.2 (VOUT), J3.2, JP1.2, LDO-C2.2, LDO-C3.+, LED2.A, OPAMP-L1.1, S1-R1.1, S2-R1.1

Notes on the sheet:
two buttons
AVR n-Fets for the display
P-Fet to power the soldering iron
5V Power Supply
ISP Header
OpAmp for temp measurement (amp factor 431)
Display 3x 7 Segment
not used pads for another circuit at the lm324

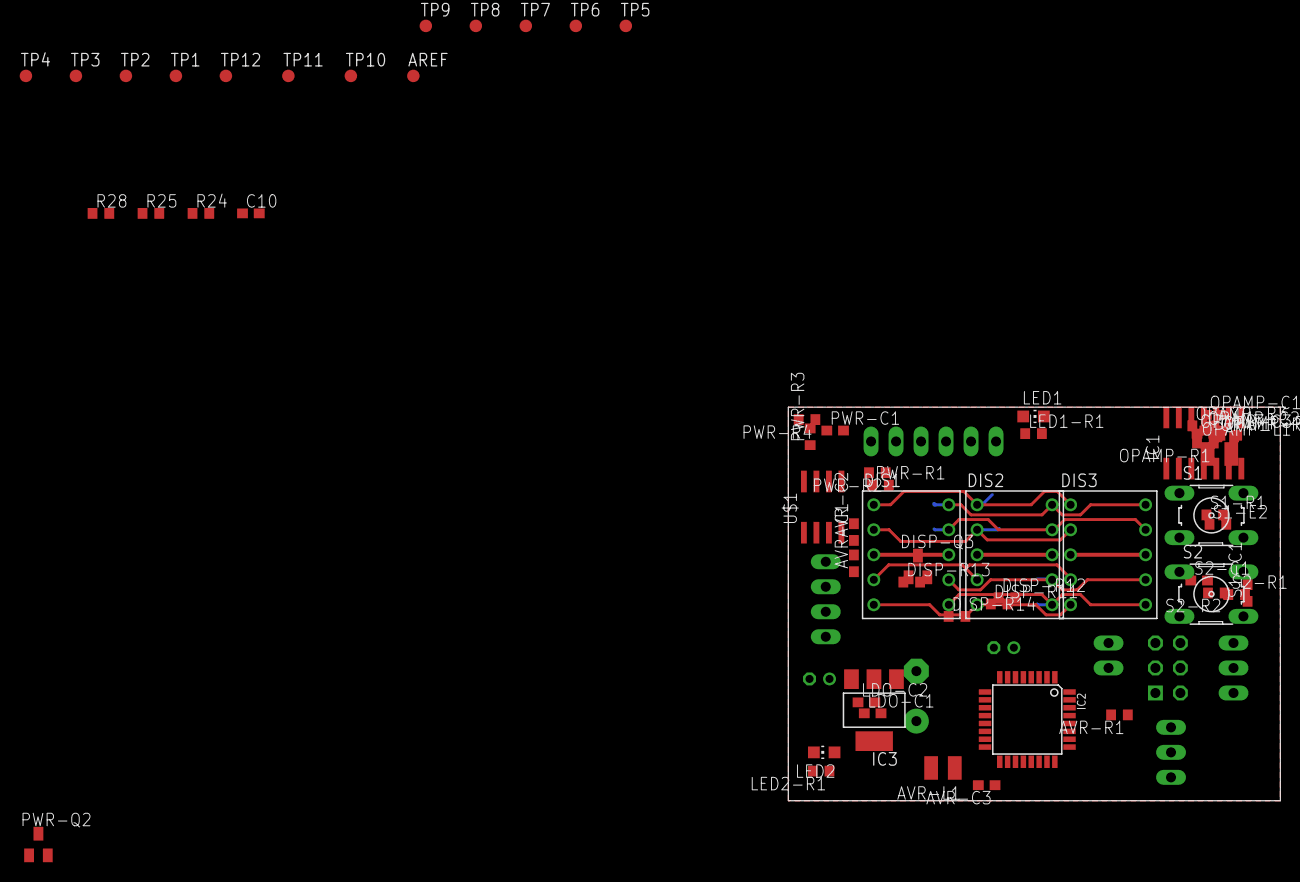
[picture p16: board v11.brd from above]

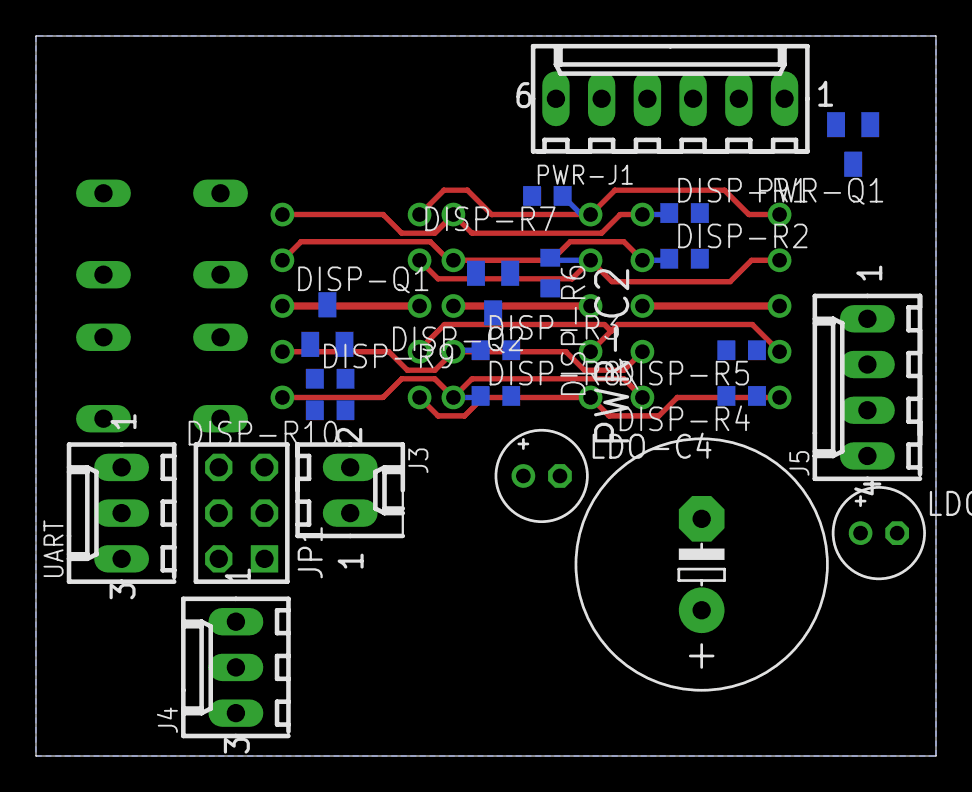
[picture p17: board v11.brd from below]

Board: 2 copper layers, 50.0 x 40.0 mm, 84 parts (22 on the bottom side), 60 nets.

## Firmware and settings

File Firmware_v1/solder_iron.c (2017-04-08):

/*
 * solder_iron.c
 *
 * Created: Do 29. Jan 14:23:00 CET 2015
 * Author: Karsten Hinz <k.hinz tu-bs.de>
 *         Georg von Zengen <oni303@gmail.com>
 */

#include <util/delay.h>
#include <avr/eeprom.h>
#include <avr/wdt.h>
#include <avr/io.h>
#include <avr/interrupt.h>

#include "config.h"
#include "eeprom-config.h"
#include "display.h"
#include "adc.h"
#include "temperature.h"
#include "uart.h"
#include "timing.h"
#include "buttons.h"
#include "menu.h"
#include "tip.h"
#include "clock.h"
#include "controller.h"

#include "grip.h"

#ifdef ROTARY_ENCODER
	#include "rotary_encoder.h"
#endif


void on_watchdog_reset(void);
void from_menu(void);
/******************VERY IMPORTANT********************************************
 * this code block is necessary to prevent the processor to run into watchdog-reset-lifelock
 * do NOT delete this block
****************************************************************************/
void wdt_init(void) __attribute__((naked)) __attribute__((section(".init3")));

void wdt_init(void)
{
	wdt_reset();
	wdt_enable(WDTO_8S);
    return;
}
/*******************end of very important block***************************/
int16_t temperature = 0;
int16_t temperature_save = 0;

void plus(void)
{
  temperature = tip_getTargetTemp();
  if (temperature != TEMP_MAX) {
  	temperature++;
	display_temperature(temperature);
	tip_setTargetTemp(temperature);
  }
}

void minus(void)
{
  temperature = tip_getTargetTemp();
  if (temperature != TEMP_MIN) {
    temperature--;
	display_temperature(temperature);
	tip_setTargetTemp(temperature);
  }
}

void back_to_default(void)
{
	temperature = config.default_temp;
	tip_setTargetTemp(temperature);
	display_temperature(temperature);
}

void goto_menu(void)
{
	tip_disable();
	menu_init(&from_menu);
}
void from_menu(void)
{
	buttons_init(&plus, &minus, &back_to_default, &goto_menu);
#ifdef ROTARY_ENCODER
	encode_init(&plus, &minus, &back_to_default, &goto_menu);
#endif
	tip_enable();

}

int main(void)
{
	int16_t old_temp = 0;
	on_watchdog_reset();
	wdt_enable(WDTO_500MS);
	config_init();
	config_load();
	config_reset();	// make sure to use default settings for now
	display_init();
	clock_init();
	buttons_init(&plus, &minus, &back_to_default, &goto_menu);
#ifdef ROTARY_ENCODER
	encode_init(&plus, &minus, &back_to_default, &goto_menu);
#endif
	uart_init(19200, one_stop_bit_e, no_parity_e);

	next_time_t new_temp_timer;
	timer_init(&new_temp_timer,1,0,0); // 1s
	timer_prepare();
	next_time_t temp_timer;
	timer_init(&temp_timer,0,32,0); // 0.25s
	timer_prepare();
	timer_set(&temp_timer);

	temperature = config.default_temp;
	tip_setTargetTemp(temperature);
	tip_enable();
	control_init();  // this heats things up!

	grip_init();

	uint8_t temp_to_show = 0;
	display_sign(2, SIGN_H);
	display_sign(1, SIGN_I);
	display_sign(0, SIGN_EXCLAMATION);
	printf("booted\r\n");
	while(1)
	{
		if (!in_menu){
			if (old_temp != temperature){
				old_temp = temperature;

				timer_set(&new_temp_timer);
				temp_to_show = 1;
			}

			if (grip_getState()) { // will be true, if nothing is connected to grip pin
				tip_setTargetTemp(temperature);
			} else {
				tip_setTargetTemp(TEMP_REST);
			}

			if(timer_past(&new_temp_timer)){
				temp_to_show = 0;
				timer_set(&temp_timer);
			}
			if(temp_to_show == 0){
				if(timer_past(&temp_timer)){
					timer_set(&temp_timer);
					switch (tip_getState()) {
					case TIP_CONNECTED:
						display_temperature(tip_getTemp());
						break;
					case TIP_DISCONNECTED:
						display_sign(2, SIGN_MINUS);
						display_sign(1, SIGN_MINUS);
						display_sign(0, SIGN_MINUS);
						break;
					case TIP_BROKEN:
						display_sign(2, SIGN_T);
						display_sign(1, SIGN_I);
						display_sign(0, SIGN_P);
						break;
					}
				}
			}
		}

#ifdef ROTARY_ENCODER
		check_rotary_timer();
#endif

		wdt_reset(); //still alive

	}
}


/*******************************************
This function holds the soldering station
from heating and forces the user to power
cycle it
*******************************************/
void on_watchdog_reset(void)
{
	if(MCUSR & (1 << WDRF)){ //stay in ERROR-mode when reseted by watchdog until power cycle
		wdt_enable(WDTO_8S);
		MCUSR &= ~(1 << WDRF);
		DDRD |= (1 << PD4);
		PORTD &= ~(1 << PD4); //make sure tip is off
		config_load();
		display_init();
		clock_init();
		uart_init(19200, one_stop_bit_e, no_parity_e);
		sei();
		while(1){ // give a hint that a power cycle is necessary
			wdt_reset();
			printf("ERROR: please power cycle this device\r\n");
			display_sign(2,SIGN_E);
			display_sign(1,SIGN_R);
			display_sign(0,SIGN_R);
			_delay_ms(700);
			display_sign(2,SIGN_T);
			display_sign(1,SIGN_R);
			display_sign(0,SIGN_N);
			_delay_ms(700);
			display_sign(2,SIGN_O);
			display_sign(1,SIGN_F);
			display_sign(0,SIGN_F);
			_delay_ms(700);
			display_sign(2,SIGN_A);
			display_sign(1,SIGN_N);
			display_sign(0,SIGN_D);
			_delay_ms(700);
			display_sign(2,0);
			display_sign(1,SIGN_O);
			display_sign(0,SIGN_N);
			_delay_ms(700);
		}
	}
}

void set_temperatur(int16_t temp)
{
	temperature_save = temp;
}

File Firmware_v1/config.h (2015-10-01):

#pragma once

// #define HW_VERSION 1
#define HW_VERSION 12 // current hardware version

// Uncomment to use rotary encoder instead of button for temperature setting
//#define ROTARY_ENCODER 1

// Change if you want to disable resting.
#define GRIP_ENABLE 1

// the temperature the system is supposed to not exceed
#define TEMP_MAX 380

// temperature that should be held when resting
#define TEMP_REST 150

// lowest temperature allowed
#define TEMP_MIN 0

// default power on temperature
#define DEFAULT_TEMP 300
#define SAVED_TEMP0 350
#define SAVED_TEMP1 250

// when the measured temperate exceeds this value, it is assumed that not tip is detected
// measured temperature rises to maximum without a tip because the opamp saturates
#define NO_TIP_TEMP 450

// minimum observed temperature rise per second to assume that the tip is connected correctly
// it is possible to connect the tip only half way which leads to wrong temperature readings
// this must be avoided as it can harm the tip
#define MIN_TEMP_PER_SECOND 5

// maximum realistic temperature change per second
//if the temperature changes too fast, something hardware wise must be wrong
#define MAX_TEMP_PER_SECOND 20

//PID-Controller values
#define PID_P 350
#define PID_I 2
#define PID_D 10

// threshold at which the hall sensor is supposed to trigger
// if set to 0 rest detection will be disabled
#define REST_HALL_THRESHOLD 15

// temperature is calculated from the adc reading via a linear function: temp = m * adc + b
#define TEMP_CONVERSION_B 49.9424k
#define TEMP_CONVERSION_M 0.4433k

// temperature scale
// if defined the display will work in fahrenheit
//#define TEMP_KELVIN
#define TEMP_CELSIUS
//#define TEMP_FAHRENHEIT
//#define TEMP_RANKINE
//#define TEMP_DELISLE
//#define TEMP_REAMUR
//#define TEMP_NEWTON
//#define TEMP_ROMER

#include "pinout.h"

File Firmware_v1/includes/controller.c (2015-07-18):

/*
 * controller.c 
 *
 * Created:  Sat Jan 31 23:03:24 2015
 * Author: Georg von Zengen < oni303@gmail.com>
 *         Yannic Schröder <yannic@dontclickthis.de>
 *
 *
 * WARNING: messing around in this file may cause damage to the tip.
 * This code comes WITHOUT any warranty at all.
 * The author is not responsible for any harm it causes to you, people surrounding you, or anything else.
 */ 

#include <avr/io.h>
#include <avr/interrupt.h>

#include "config.h"
#include "eeprom-config.h"
#include "tip.h" 
#include "timer0.h"
#include "uart.h"

#define Ta 100 //ms  //control cycle time
#define Trand ((Ta*32)/255)

#define MAXESUM 10 //*Ta ms  // maximum of error integration most not be too high because the tip heats very fast.
#define MINESUM (-1*MAXESUM)

static int16_t esum = 0;
static int16_t eold = 0;

static volatile uint8_t pwm_value = 0;					// current heating value (0-255)

static uint16_t pwm_count = 0;							// counter for the software pwm
static volatile uint8_t measurement_finished = 0;

static void control(int16_t temp);

void new_temperature_ready_callback(int16_t temp){
	control(temp);				//calculate a new y
	measurement_finished = 1;	//temperature measurement is finished
}

void control_init(void)
{
	OCR0A = Trand;
	TCCR0A |= (1 << WGM01); //CTC mode
	TIMSK0 |= (1 << OCIE0A) ;
	tip_init(&new_temperature_ready_callback);
	tip_startConversion();
	timer0_init();
	printf("controller booted\r\n");
}

static void control(int16_t temp)
{
	// current error is target temperature minus measured temperature
	int16_t e = tip_getTargetTemp() - temp;

	// prevent esum over- and underflows
	if(esum >= (int32_t)(MAXESUM - e)){
		esum = MAXESUM;
	} else if(esum <= (int32_t)(MINESUM + e)){
		esum = (MINESUM);
	}
	// make sure esum is not increased if maximum heating is reached to prevent overshooting
	else if(((pwm_value > 0) && (pwm_value < 255) ) || ((pwm_value == 255) && (e < 0)) || ((pwm_value == 0) && (e > 0))) {
		esum += e;
	}
	
	// calculate P, I and D values
	int16_t p = ((int32_t)((int32_t)config.pid_p*(int32_t)e))/(int32_t)128;
	int16_t i = (int32_t)((int32_t)config.pid_i*(int32_t)Ta*(int32_t)esum)/(uint32_t)128;
	int16_t d = (int32_t)(config.pid_d*(e - eold)/Ta)/(uint32_t)128;

	// add P, I and D for new output value
	int16_t y = (int32_t)((int32_t)p + (int32_t)i + (int32_t)d);

	// update error
	eold = e;

	// clamp y between 0 and 255 for the pwm value
	if(y > 255){
		y = 255;
	} else if (y < 0){
		y = 0;
	}

	// only heat if tip is under maximum temperature
	if (temp > TEMP_MAX) {
		y = 0;
	}

	// store new value for the pwm loop
	pwm_value = y;
}

ISR(TIMER0_COMPA_vect) {
	uint8_t increment = 1; // sometimes the counter is not incremented in the current cycle

	// power tip on timer overflow if the temperature is already measured and the duty cycle is over 2 (avoids a clicking noise of the tip)
	if( (pwm_count == 0) && measurement_finished && (pwm_value > 2) ){
		measurement_finished = 0;
		tip_powerOn();
	}
	// if the timer overflows and the measurement is not yet finished wait and do nothing (should not happen)
	else if( (pwm_count == 0) && !measurement_finished ){
		increment = 0; //make sure pwm_count is not increased (clean overflow)
	}
	// unpower tip if duty cycle is over
	else if (pwm_count == pwm_value) {
			tip_powerOff();
	}
	// measure temperature some time after unpowering to allow the voltage to settle
	// powering the tip saturates the opamp, so measurement is only possible when not powered
	else if (pwm_count == pwm_value + 50) {
			tip_startConversion();
	}
	// start a new cycle if measurement is finished  and the cycle is over by overflowing the counter manually
	else if( measurement_finished && (pwm_count >= 255) ){
		pwm_count = 0; // emulate a timer overflow
		increment = 0; // make sure pwm_count is not increased (clean overflow)
	}

	// only increment the counter if needed
	if (increment) {
		pwm_count++;
	}
}

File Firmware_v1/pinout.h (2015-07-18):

#pragma once

#if (HW_VERSION == 1)
	#define LED_DDR   DDRC
	#define LED_PORT  PORTC
	#define LED0      (1<<PC3)
	#define LED1      (1<<PC4)
	#define LED2      (1<<PC5)

	#define DISP_DDR  DDRB
	#define DISP_PORT PORTB
	#define DISP_DOT  (1<<PB0)
	#define DISP_BR   (1<<PB1)
	#define DISP_BL   (1<<PB6)
	#define DISP_UR   (1<<PB3)
	#define DISP_UL   (1<<PB4)
	#define DISP_TOP  (1<<PB5)
	#define DISP_MID  (1<<PB2)
	#define DISP_BOT  (1<<PB7)
//	#define DISP_TOP  (1<<PB2)

	#define SENS0     PC0 // ADC0
	#define HALL      PC1 // ADC1

	#define PWR0_DDR  DDRD
	#define PWR0_PORT PORTD
	#define PWR0      PD4

//	#define BUTTON_UP (1<<PD2) // INT0
//	#define BUTTON_DN (1<<PD3) // INT1

// not used
//	#define J11       ADC7
//	#define J21       PD0 // RX
//	#define J22       PD1 // TX
//	#define J41       PD5
//	#define J42       PD6
//	#define J43       PD7

#elif (HW_VERSION == 12)
	#define LED_DDR   DDRD
	#define LED_PORT  PORTD
	#define LED0      (1<<PD7) // the lcd on the right
	#define LED1      (1<<PD6) // the lcd in the middle
	#define LED2      (1<<PD4) // the lcd on the left

	#define DISP_DDR  DDRB
	#define DISP_PORT PORTB
	#define DISP_DOT  (1<<PB4)
	#define DISP_BR   (1<<PB1)
	#define DISP_BL   (1<<PB7)
	#define DISP_UR   (1<<PB3)
	#define DISP_UL   (1<<PB0)
	#define DISP_TOP  (1<<PB2)
	#define DISP_MID  (1<<PB5)
	#define DISP_BOT  (1<<PB6)

	#define SENS0     PC0 // ADC0
	#define HALL      PC1 // ADC1

	#define PWR0_DDR  DDRD
	#define PWR0_PORT PORTD
	#define PWR0      PD5

	#define BUTTON_PORT PORTD
	#define BUTTON_PORT_DDR DDRD
	#define BUTTON_PIN PIND
	#define PLUS_PIN PD2
	#define MINUS_PIN PD3

	#define PLUS_INTERRUPT_VECT INT0_vect
	#define MINUS_INTERRUPT_VECT INT1_vect

	#ifdef ROTARY_ENCODER
		#define ROTARY_A_PIN     PINC
		#define ROTARY_B_PIN     PINC
		#define ROTARY_BUTTON_PIN		PINC
		
		#define ROTARY_A_PIN_NR     PC2
		#define ROTARY_B_PIN_NR     PC3
		#define ROTARY_BUTTON_PIN_NR	PC4
		
		#define ROTARY_A_PORT     PORTC
		#define ROTARY_B_PORT     PORTC
		#define ROTARY_BUTTON_PORT		PORTC
		
		#define ROTARY_A_DDR     DDRC
		#define ROTARY_B_DDR     DDRC
		#define ROTARY_BUTTON_DDR		DDRC
	#endif
	

// not used
//	#define J11       ADC7
//	#define J21       PD0 // RX
//	#define J22       PD1 // TX
//	#define J41       PD5
//	#define J42       PD6
//	#define J43       PD7
#endif

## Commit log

2014-11-08 The actual state of the hardware. Still not tested. Will most likely only work in theory and should be built on a breadboard first.
    [v1.brd, v1.sch]
2014-11-17 slight changes in the layout
    [v1.brd, v1.sch]
2014-11-17 shopping list for reichelt.de and farnell.com added with some comments
    [ShoppingList.csv]
2014-11-17 slight changes to the shopping list
    [ShoppingList.csv]
2014-11-17 finish layer done so pcb will have the components names printed on it
    [v1.brd, v1.sch]
2014-11-17 op-amp rework
    [v1.brd, v1.sch]
2014-11-18 latest version with some updates
    [v1.brd, v1.sch]
2014-11-18 temperatures of the thermo element inside the soldering iron
    [Temperature.ods]
2014-11-18 updated wires used for the iron
    [ShoppingList.csv]
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2014-11-18 completed shopping list including prices
    [ShoppingList.csv]
2014-11-18 updated shopping list
    [ShoppingList.csv]
2014-11-18 fixed power level descibtion
2014-11-18 some resistor sizes changed from 0402 to 0603
    [v1.brd, v1.sch]
2014-11-18 updated shopping list including aliexpress parts and itead pcb
    [ShoppingList.csv]
2014-11-20 some ground issues fixed
    [v1.brd]
2014-12-09 moved 1 label off a pad
    [v1.brd]
2015-01-09 Full shopping list for German supplier Reichelt.de and some Aliexpress items.
    [ShoppingList.ods]
2015-01-29 config file for all global defines that might change when pcb gets updated
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2015-01-30 Added a 100nF cap to AREF (see issue #4). Added an extra LED to see if 5V is supplied.
    [v1.brd, v1.sch]
2015-01-30 Changed resistors at the LED display to 300 Ohm to reduce power drain under 5V supply. Changed the position of the LED showing the duty cycle of the p-fet slightly to make it easier to solder it on.
    [v1.brd, v1.sch]
2015-01-30 Some minor changes to solve issues with overlapping components (especially smd components under polarized capacitors).
    [v1.brd]
2015-01-30 added a "v1.0 - 01/2015" label
    [v1.brd]
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2015-02-01 Changed the pinout.h a little bit (regarding the config for the buttons) and added two files to catch the interrupts coming from the buttons. I didn't test that. So it might be buggy.
    [pinout.h]
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2015-02-01 - made this piece of code less general and more specific to hw_version 1. - also completed the settings necessary to use interrupts for external pins PD2 and PD3 - corrected an error - filled the int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
2015-02-02 full shopping list
    [ShoppingList.ods]
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2015-02-03 solved all from #17
    [v1.brd, v1.sch]
2015-02-03 fixed includes in uart.h
    In the former version stdio.h had to be include before uart.h in every
    file using uart.h.
    Now it is only necessary to include uart.h
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2015-02-04 Generalized button configuration. Button pins and port can now be configured in header file. Additionally, NULL pointers for functions pointers are caught. Fixing issues #20
2015-02-04 Fixed issue #35 and added a third pin to make GND accessible when using UART.
    [v1.brd, v1.sch]
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2015-02-04 now all 10 pcbs are allocated to people
    [ShoppingList.ods]
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2015-02-09 Changed description in schematic from German to English.
    [v1.sch]
2015-02-09 PID with tip noise avoidance
    For the new random overall length of the PWM COMP0A and COMP0B are
    needed. Thus the display update routine now needs to be called by the
    software timers.
    [controller.c]
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2015-02-09 some noise related adjustments
    [controller.c]
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2015-02-09 better limitation of esum and correction of D part
    [controller.c]
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2015-02-10 fixes issue #56
    [v1.brd, v1.sch]
2015-02-11 added multi temperature scale support (funny-scale-support) from issue #58. celsius is set right now.
    please use display_temperature(int16_t number), when displaying a temperature!!
    [config.h, rest_check.c, solder_iron.c]
2015-02-12 - changed the 6pin header to a 7pin header to deliver 5V as well on one pin (see #60) - reduced sensor wire from 1mm to 0.8mm - rearrange wiring to compensate changes
    [v1.brd, v1.sch]
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2015-02-13 all changes described in #64 pull ups are 10k
    [v1.brd, v1.sch]
2015-02-13 changed schematic (#65)
    no real changes
    [v1.brd, v1.sch]
2015-02-14 Closes #14 by activating the watchdog
    After the AVR was reseted by the watchdog the tip is not heated again
    until the device was power cycled. Until then an error is displayed.
    [solder_iron.c]
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2015-04-28 last changes on layout v1.1
    [v11.brd, v11.sch]
2015-04-28 new layout v1.2 including opa336u for boosting including seperate 7segment displays including test points
    [v12.brd, v12.sch]
2015-04-28 new temperature measurements
    [Temperature.ods]
2015-04-28 something .. i dont know ?!
    [v1.brd, v1.sch]
2015-04-28 slight changes
    [v12.brd]
2015-04-28 changed diode to a minimelf diode from open parts library
    [v12.brd, v12.sch]
2015-04-28 slight renaming for better understanding
    [v12.brd, v12.sch]
2015-04-29 added silk screen to test points and optimized ground connections
    [v12.brd, v12.sch]
2015-04-29 software readout of safety circuit additional led displaying state of safety circuit connecting soldering tip power switch to timer output OC0B
    [v12.brd, v12.sch]
2015-04-29 updated shipping list .. not fully done
    [ShoppingList.ods]
2015-04-29 changed some values (led resistors) updated shopping list
    [ShoppingList.ods, v12.brd, v12.sch]
2015-04-30 latest updates for finished hardware version 1.2
    [v12.brd, v12.sch]
2015-04-30 gerber files for version 1.2
    [v12.GBL, v12.GBO, v12.GBP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]
2015-04-30 last changes
    [v12.brd, v12.sch]
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2015-05-20 Slight changes to correct values of some capacitors.
    [v12.brd, v12.sch]
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2015-06-02 some new temperatures measured behind the OPA336U
    [Temperature.ods]
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2015-06-10 correct pin numbering and description of segments
    [pinout.h]
2015-06-10 adding a third temperature curve
    [Temperature.ods]
2015-06-27 new temperature calibration for new opamp
    [Temperature.ods]
2015-06-27 disabled tip detection as it is not working currently
    [controller.c, tip.c]
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2015-07-11 reworked the schematic and had to reconnect some signals in the layout. no substantial changes
    [v12.brd, v12.sch]
2015-07-12 created hardware version 1.3
    it is basically v1.2 plus a jumper with which one can disable the safety circuit (after cutting a wire and soldering in a pin header for reconnecting the wire later)
    [v13.brd, v13.sch]
2015-07-13 change a printed info on the board
    [v13.brd]
2015-07-14 added 5v pin header for twi added optional pull-ups for twi moved some parts around and rerouted some wires
    [v13.brd, v13.sch]
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2015-07-17 [hardware] Adds A4 frame to schematic, Signalnames
    and changed name of signal of pwm output to PWM_OUT
    [v13.brd, v13.sch]
2015-07-18 software: reworked include logic for config and pinout
    pinout is now part of config and only config will be included everywhere
    [config.h, controller.c, pinout.h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]
2015-07-18 software: fixed typo in adc
    [adc.c, adc.h, rest_check.c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]
2015-07-18 software: reworked controller, reworked tip, readded tip detection and sanity checks
    this fixes #77
    [config.h, controller.c, solder_iron.c]
2015-07-19 changed radius of round corners changed location of the drilling holes slightly cleared some space around the drilling holes added 2x 10k to set all unused LM324 inputs to a 2,5V moved some component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
    [v13.brd, v13.sch]
2015-09-05 changed arrangement of parts to be almost all vertical
    [v13.brd]
2015-09-23 changed the place of some resistors
    [v13.brd]
2015-10-01 change some resistor values moved the leds to lower left corner
    [v13.brd, v13.sch]
2015-10-01 correction in header added grip.h removed some white spaces made rest detection stop heating
    [solder_iron.c]
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2015-10-02 added unmounted resistors around hall sensor wire added more labels changed some wires to comply with elecrow drc added heat sink for low drop, which is not connected to anything else
    [v13.brd, v13.sch]
2015-10-02 gerber files for version 1.3 as of 01. Oct. 2015
    [v13.GBL, v13.GBO, v13.GBS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]
